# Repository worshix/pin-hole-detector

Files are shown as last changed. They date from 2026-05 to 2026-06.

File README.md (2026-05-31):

# PIN HOLE DETECTOR

A Django dashboard and ESP32-CAM firmware starter for capturing high-quality plastic roll images and storing them for future defect-model training.

## Firmware

Open `firmware/pinhole-detector-espcam/pinhole-detector-espcam.ino` in Arduino IDE.

Required Arduino libraries:

- ESP32 board package
- PubSubClient

Use board settings for an AI Thinker ESP32-CAM style module. The sketch connects to Wi-Fi `pinhole-detector`, listens to MQTT topic `pinhole/control`, and uploads JPEG frames to `http://192.168.137.1:8000/api/images/receive/` once per second after receiving `start`.

## Django app

```powershell
python -m venv .venv
.\.venv\Scripts\Activate.ps1
pip install -r requirements.txt
python manage.py migrate
python manage.py runserver 0.0.0.0:8000
```

Open `http://127.0.0.1:8000/` for the dashboard.

## MQTT

The dashboard publishes `start` and `stop` to topic `pinhole/control` on broker `192.168.137.1:1883`. Make sure Mosquitto is running and reachable from both the PC and ESP32-CAM.

## Image upload API

Endpoint: `/api/images/receive/`

The ESP32-CAM can post raw JPEG bytes with `Content-Type: image/jpeg`. Uploaded files are stored under `media/captures/` and shown on the dashboard/history pages.

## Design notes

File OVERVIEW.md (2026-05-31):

# Pinhole Detector In Plastic Roll

- We are using an esp32 to check for pinholes in a plastic roll.

## ESP32Pin Connections

| Pin | Component |
|-----|---|
| 4 | Light Relay |
| 5 | Motor (Moves the Plastic) |
| 18 | Start / Stop Button |
| 21 | SDA 20 x 4 LCD Display |
| 22 | SCL 20 x 4 LCD Display |
| 25  | Buzzer |
| 26 | Stop Indicator |
| 27 | Start Indicator |
| 34 | LDR 1  |
| 35 | LDR 2  |

## ESP32-CAM-MB
noconnections here just power

wifi name is "pinhole-detector"
wifi password is "pinhole123"
borker Ip Address is 192.168.137.1
I am using mosquitto broker for communication

## How it works

- The job of the esp32 is hole detection. If there is a hole the light will increase.
- Youy start by recording the ambient light then you start checking if light has increased. 
- We are using an LDR to detect the light.
- An increase in light means there has been a pinhole detected. If that happens you do not stop the motor but you do alert the user using buzzer and stop LED.
- The espcam is only used for taking pictures of the plastic every second and sending it to the application for dfect detection using A trained model
- esp32 cam only starts when taking pics when we hit start.
- It will get this information from the mqtt broker

## Application

- The application is made using django.
- The application has a dashboard showing the status of the esp32 and the images from the espcam
- The dashboard also displays a summary of all defects found and pinholes found. 
- The application also has a history page showing all the defects and pinholes found. 
-  All images should be stored in a folder as well.
-  I will finish the model training later but for now I need you to develop a full user interface and a route that receives images from esp32-cam-mb and stores them in a folder. 
- The route should be /api/images/receive
- I need high quality images so the model can be trained on them.
- There should also be a start and stop button on the dashboard to control the esp32.
- The esp32 should be able to send messages to the application via mqtt broker.
- The esp32 should be able to receive messages from the application via mqtt broker.

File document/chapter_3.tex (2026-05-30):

% Chapter 3: Methodology
% Required packages in main document: graphicx, float, geometry, setspace, hyperref

\chapter{Methodology}

\section{Introduction}

This chapter presents the methodology adopted in the design and development of the automated pinhole detection system for banknote paper quality control. The system integrates embedded hardware, computer vision, machine learning, and wireless communication technologies to achieve reliable and automated detection of pinholes in paper. The methodology covers the overall system architecture, the working principle of pinhole detection, the hardware components selected and their individual roles, the software design, and the mechanical structure of the system.

\section{System Architecture}

The system is composed of two main subsystems: a hardware detection unit and a software processing unit, which communicate over a Wi-Fi network.

The hardware detection unit consists of an ESP32 microcontroller, an ESP32-CAM module, a bright light source, Light Dependent Resistors (LDRs), a wiper motor, a relay module, a buck converter, a 12V power supply, and a 20$\times$4 I\textsuperscript{2}C LCD display. The wiper motor drives the paper through the detection chamber, where the bright light shines through the paper from one side while LDR sensors on the opposite side measure transmitted light intensity to detect pinholes.

The ESP32-CAM captures images of the paper under inspection and transmits them to the software unit via an HTTP API route over Wi-Fi. The software unit, running on a host computer, receives the images, processes them through a trained machine learning model built with Python, and returns detection results. The software communicates commands back to the detection hardware using the MQTT protocol, enabling real-time closed-loop control of the system.

\section{Working Principle of Pinhole Detection}

The fundamental principle behind the system is light transmission through pinholes. During normal operation, the bright light source illuminates one side of the banknote paper while the paper travels through the detection chamber driven by the wiper motor. Under a defect-free section of paper, the paper absorbs or scatters most of the light, resulting in a low reading at the LDR sensors on the opposite side.

When a pinhole is present in the paper, light passes directly through the hole and reaches the LDR sensors on the other side with a measurably higher intensity. This increase in detected light intensity triggers a detection event. The LDR readings are continuously monitored by the ESP32, which simultaneously operates the ESP32-CAM to capture an image of the suspect region. The image is then forwarded to the software system for further classification and confirmation via the trained machine learning model.

This dual approach — combining real-time LDR-based light sensing with image-based machine learning classification — ensures both speed and accuracy in pinhole detection.

\section{Hardware Components}

The following subsections describe each hardware component used in the system, its specifications, and its specific role in the detection process.

\subsection{Light Dependent Resistors (LDRs)}

\begin{figure}[H]
    \centering
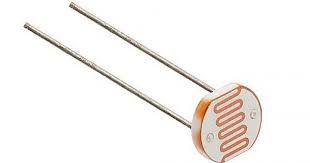
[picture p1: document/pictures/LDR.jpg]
    
    \caption{Light Dependent Resistor (LDR)}
    \label{fig:ldr}
\end{figure}

A Light Dependent Resistor (LDR), also known as a photoresistor, is a passive electronic component whose electrical resistance decreases as the intensity of incident light increases. As shown in Figure~\ref{fig:ldr}, the LDR is a compact, disc-shaped component with a characteristic serpentine conductive track on its surface.

In this system, LDRs are positioned on the side of the paper opposite to the bright light source. During normal scanning, the paper blocks most of the light and the LDRs register a high resistance (low voltage output). When light passes through a pinhole, the resistance of the corresponding LDR drops sharply, producing an elevated voltage that the ESP32 detects as an anomaly. Multiple LDRs are arranged across the width of the paper to provide full coverage of the inspection area.

\subsection{Bright Light Source}

\begin{figure}[H]
    \centering
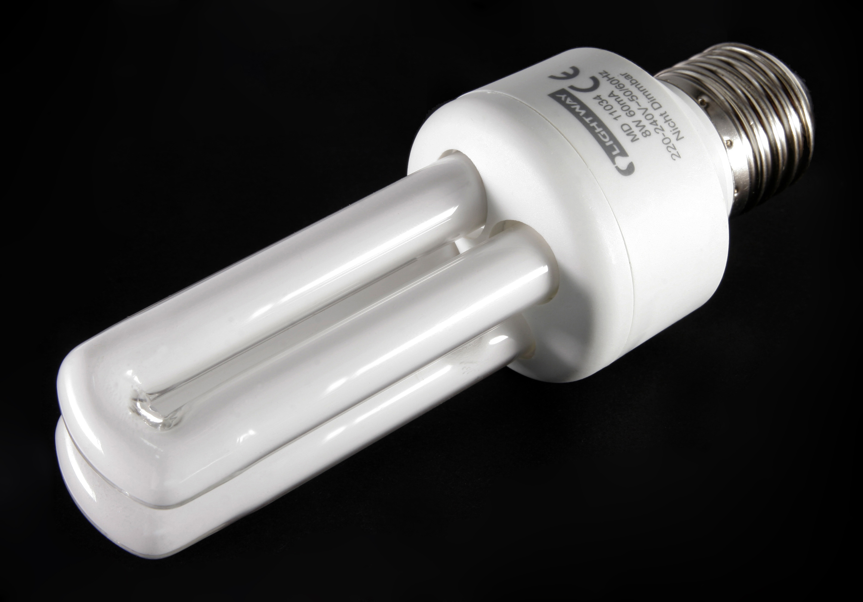
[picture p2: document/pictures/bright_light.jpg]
    
    \caption{Bright Light Source used for paper illumination}
    \label{fig:light}
\end{figure}

A high-intensity compact fluorescent lamp (CFL) is used as the light source, as shown in Figure~\ref{fig:light}. The bright light source is positioned on one side of the paper transport path, directing a uniform beam of light through the paper. A bright and consistent light source is essential to maximise the contrast between normal paper (which absorbs most of the light) and areas with pinholes (which allow the light to pass through). The CFL provides sufficient luminous intensity to ensure reliable LDR response and clear imaging by the ESP32-CAM.

\subsection{ESP32-CAM}

\begin{figure}[H]
    \centering
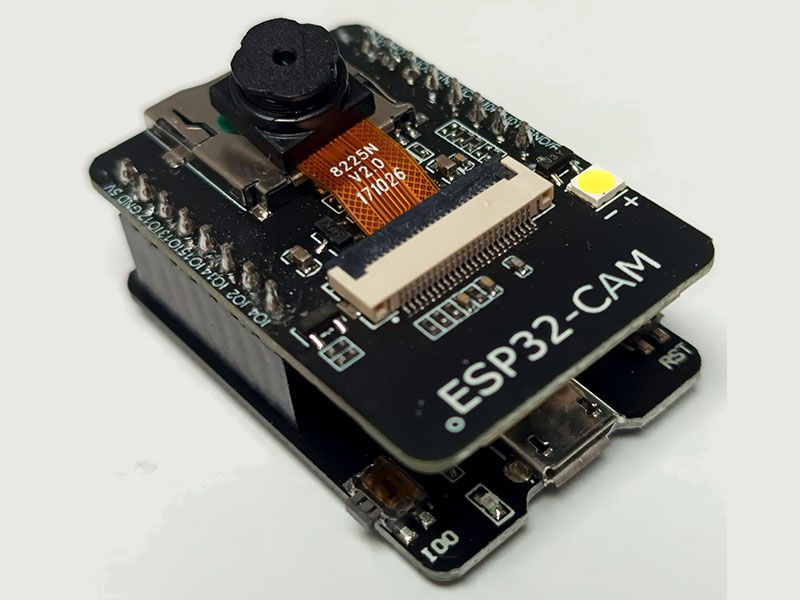
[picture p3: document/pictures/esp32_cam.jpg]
    
    \caption{ESP32-CAM Module}
    \label{fig:espcam}
\end{figure}

The ESP32-CAM, shown in Figure~\ref{fig:espcam}, is a small, low-cost microcontroller module that integrates an ESP32-S chip with an OV2640 camera and built-in Wi-Fi and Bluetooth capabilities. It is capable of capturing images and streaming video over a network.

In this system, the ESP32-CAM is mounted within the detection chamber and oriented to capture images of the paper surface during inspection. When triggered by the ESP32 (upon an LDR anomaly detection), the module captures a still image and transmits it to the host computer software via an HTTP POST request to a dedicated API endpoint. This allows the machine learning model to perform a secondary visual confirmation of detected pinholes.

\subsection{ESP32 Microcontroller}

\begin{figure}[H]
    \centering
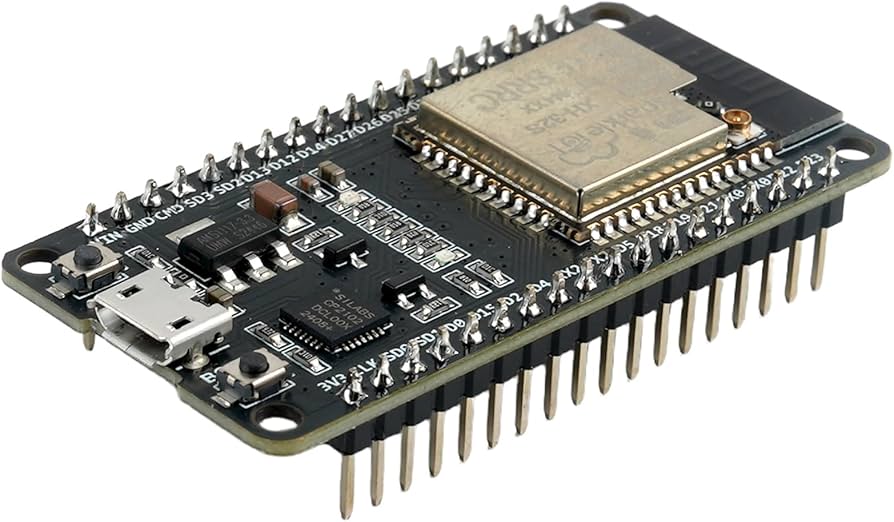
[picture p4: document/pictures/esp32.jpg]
    
    \caption{ESP32 Microcontroller}
    \label{fig:esp32}
\end{figure}

The ESP32, shown in Figure~\ref{fig:esp32}, is a powerful, low-cost, low-power system-on-chip (SoC) microcontroller with integrated Wi-Fi and Bluetooth. It features dual-core processing, numerous GPIO pins, ADC (Analogue-to-Digital Converter) channels, and support for multiple communication protocols including I\textsuperscript{2}C, SPI, UART, and MQTT.

The ESP32 serves as the central controller of the hardware unit. It reads the analogue output from the LDR sensors through its ADC channels, controls the relay module to manage the wiper motor, drives the LCD display to show system status and detection results, and communicates with the host software over Wi-Fi using the MQTT protocol. Upon receiving a detection command or result from the software, the ESP32 can trigger appropriate responses such as stopping the motor or flagging the defective paper section.

\subsection{Wiper Motor}

\begin{figure}[H]
    \centering
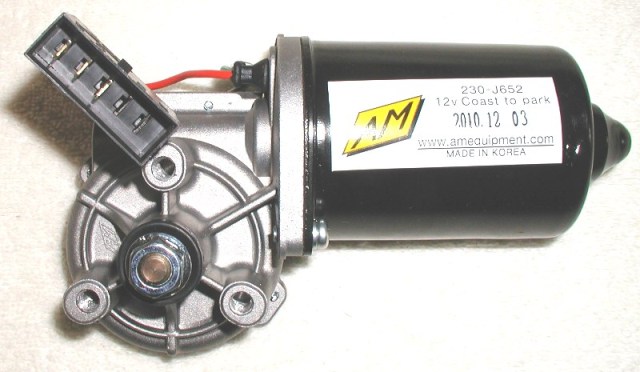
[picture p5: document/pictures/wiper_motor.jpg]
    
    \caption{Automotive Wiper Motor}
    \label{fig:wiper}
\end{figure}

An automotive wiper motor, shown in Figure~\ref{fig:wiper}, is used to drive the paper transport mechanism. Wiper motors are inherently designed to operate at low, consistent speeds — a characteristic that is essential for this application, as the paper must move slowly and uniformly through the detection chamber to allow sufficient time for the LDRs and ESP32-CAM to scan each section accurately.

The primary advantage of selecting a wiper motor over alternatives such as a standard DC motor with a Variable Frequency Drive (VFD) is that the wiper motor naturally operates at a low RPM without requiring additional speed-control circuitry. This simplifies the mechanical design and reduces overall system cost. The motor is powered by the 12V power supply and its operation is controlled via the relay module.

\subsection{Power Supply}

\begin{figure}[H]
    \centering
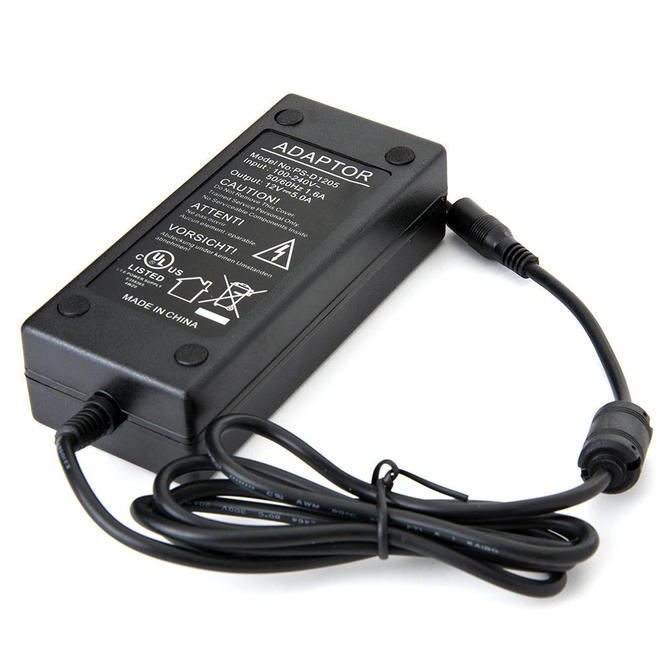
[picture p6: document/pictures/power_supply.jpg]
    
    \caption{12V DC Power Supply}
    \label{fig:psu}
\end{figure}

A 12V DC power supply, shown in Figure~\ref{fig:psu}, provides the primary power for the system. The 12V rail directly powers the wiper motor through the relay module. The same 12V supply also feeds the buck converter, which steps the voltage down to 5V for the ESP32 and other logic-level components. Using a single 12V supply for the entire system simplifies the power distribution architecture and reduces the number of external power adapters required.

\subsection{Relay Module}

\begin{figure}[H]
    \centering
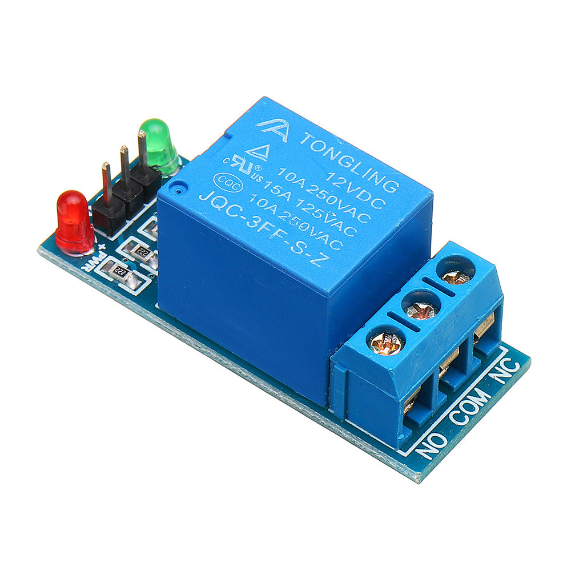
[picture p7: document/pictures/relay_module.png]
    
    \caption{12V Relay Module (5A)}
    \label{fig:relay}
\end{figure}

The relay module, shown in Figure~\ref{fig:relay}, is an electrically operated switch that allows the low-voltage ESP32 to control the high-voltage wiper motor circuit. The relay used is rated at 12V DC with a 5A current capacity, making it suitable for switching the wiper motor load safely.

When the ESP32 asserts a control signal to the relay's input pin, the relay coil is energised, closing the contact and completing the circuit between the 12V supply and the wiper motor. This enables the ESP32 to start and stop the motor as required during the detection process without any direct electrical connection between the microcontroller and the high-current motor circuit, thus protecting the ESP32 from voltage and current damage.

\subsection{\texorpdfstring{LCD 20$\times$4 I\textsuperscript{2}C Display}{LCD 20x4 I2C Display}}

\begin{figure}[H]
    \centering
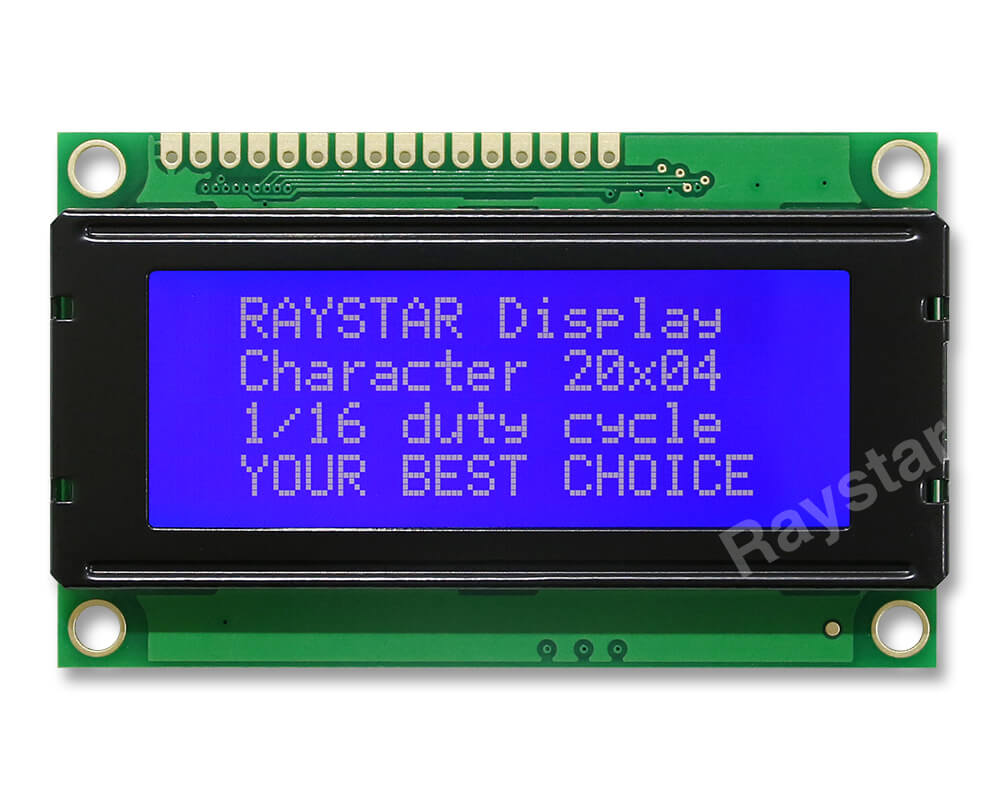
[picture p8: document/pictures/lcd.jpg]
    
    \caption{20$\times$4 Character LCD with I\textsuperscript{2}C Interface}
    \label{fig:lcd}
\end{figure}

The 20$\times$4 character LCD module with I\textsuperscript{2}C interface, shown in Figure~\ref{fig:lcd}, provides a local user interface for the detection system. The display is capable of showing 4 rows of 20 characters each, which is sufficient to present system status messages, detection results, motor state, and Wi-Fi connectivity information.

The I\textsuperscript{2}C interface requires only two signal lines (SDA and SCL) to communicate with the ESP32, minimising the number of GPIO pins used. This is particularly advantageous given that the ESP32 must also manage the LDR ADC channels, relay control, and MQTT communication simultaneously.

\subsection{Buck Converter}

\begin{figure}[H]
    \centering
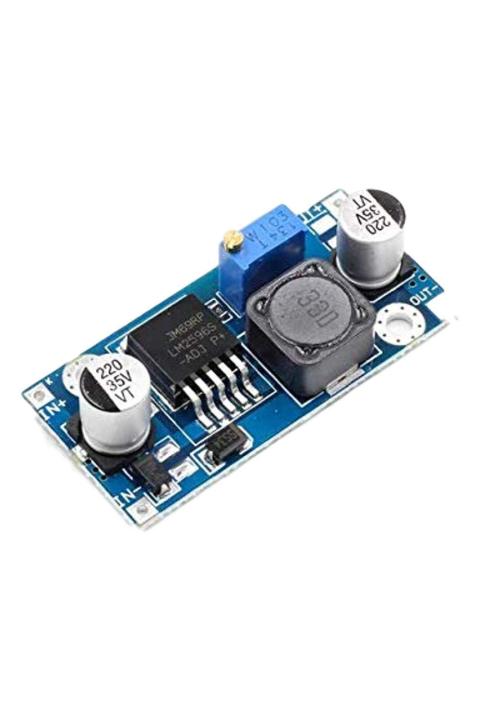
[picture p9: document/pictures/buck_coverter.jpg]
    
    \caption{DC-DC Buck Converter (12V to 5V)}
    \label{fig:buck}
\end{figure}

A DC-DC buck converter, shown in Figure~\ref{fig:buck}, is a step-down voltage regulator that efficiently converts the 12V supply voltage to the 5V required by the ESP32 microcontroller and other logic-level components. Unlike linear regulators, a buck converter achieves voltage step-down with high efficiency (typically above 85\%), generating significantly less heat and wasting less power, which is important for a continuously running embedded system.

The buck converter takes the 12V input from the primary power supply and outputs a regulated 5V to power the ESP32, LCD module, and relay control circuitry, ensuring stable operation of all electronic components throughout the detection process.

\section{Software Design}

The software subsystem is responsible for receiving images from the ESP32-CAM, classifying them using a trained machine learning model, and returning detection results to the hardware via MQTT. The software runs on a host computer connected to the same Wi-Fi network as the ESP32 and ESP32-CAM.

\subsection{Flask Web Server and API}

The software is built using Flask, a lightweight Python web framework. Flask exposes a RESTful HTTP API with a dedicated endpoint to which the ESP32-CAM sends captured images. Upon receiving an image via an HTTP POST request to the API route, the server immediately passes the image to the machine learning inference module for processing. Flask was selected for its simplicity, minimal overhead, and ease of integration with Python-based machine learning libraries.

\subsection{Machine Learning Model}

A machine learning model is trained using Python to classify captured images as either containing a pinhole or being defect-free. The model is trained on a labelled dataset of paper images, learning the visual signatures associated with pinholes under the system's lighting conditions. Once trained, the model is serialised and loaded by the Flask application at startup, ready for real-time inference on incoming images from the ESP32-CAM.

\subsection{MQTT Communication}

The Message Queuing Telemetry Transport (MQTT) protocol is used for communication from the software back to the ESP32 hardware. After the machine learning model produces a classification result, the Flask server publishes the result as an MQTT message to a broker. The ESP32, subscribed to the relevant MQTT topic, receives the message and takes the appropriate action, such as stopping the wiper motor or displaying an alert on the LCD. MQTT was chosen for its low bandwidth usage, low latency, and suitability for embedded IoT applications.

\section{Mechanical Design}

The mechanical structure of the detection system was designed using SolidWorks, a professional 3D computer-aided design (CAD) software package. The design encapsulates the paper transport mechanism, the light source housing, the LDR mounting array, the camera mount, and the electronics enclosure into a single integrated unit.

The wiper motor is mechanically coupled to a roller mechanism that drives the banknote paper through the detection chamber at a controlled, low speed. The light source is positioned on one side of the paper path within a sealed housing to prevent ambient light from interfering with LDR readings. The LDR array is mounted directly opposite the light source on a fixed bracket to maintain consistent sensor-to-paper distance during operation.

The SolidWorks model allowed for precise dimensioning and assembly verification before physical fabrication, reducing the risk of component fit issues and ensuring that the optical alignment between the light source, paper, and LDR sensors was maintained accurately throughout operation.

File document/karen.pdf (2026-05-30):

# Chapter 1

# Methodology

## 1.1 Introduction

This chapter presents the methodology adopted in the design and development of the

automated pinhole detection system for banknote paper quality control. The system

integrates embedded hardware, computer vision, machine learning, and wireless commu-

nication technologies to achieve reliable and automated detection of pinholes in paper.

The methodology covers the overall system architecture, the working principle of pin-

hole detection, the hardware components selected and their individual roles, the software

design, and the mechanical structure of the system.

## 1.2 System Architecture

The system is composed of two main subsystems: a hardware detection unit and a soft-

ware processing unit, which communicate over a Wi-Fi network.

The hardware detection unit consists of an ESP32 microcontroller, an ESP32-CAM

module, a bright light source, Light Dependent Resistors (LDRs), a wiper motor, a relay

module, a buck converter, a 12V power supply, and a 20×4 I²C LCD display. The

wiper motor drives the paper through the detection chamber, where the bright light

shines through the paper from one side while LDR sensors on the opposite side measure

transmitted light intensity to detect pinholes.

The ESP32-CAM captures images of the paper under inspection and transmits them

to the software unit via an HTTP API route over Wi-Fi. The software unit, running on

a host computer, receives the images, processes them through a trained machine learning

model built with Python, and returns detection results. The software communicates

commands back to the detection hardware using the MQTT protocol, enabling real-time

closed-loop control of the system.

## 1.3 Working Principle of Pinhole Detection

The fundamental principle behind the system is light transmission through pinholes.

During normal operation, the bright light source illuminates one side of the banknote

paper while the paper travels through the detection chamber driven by the wiper motor.

Under a defect-free section of paper, the paper absorbs or scatters most of the light,

resulting in a low reading at the LDR sensors on the opposite side.

When a pinhole is present in the paper, light passes directly through the hole and

reaches the LDR sensors on the other side with a measurably higher intensity. This

increase in detected light intensity triggers a detection event. The LDR readings are

continuously monitored by the ESP32, which simultaneously operates the ESP32-CAM

to capture an image of the suspect region. The image is then forwarded to the software

system for further classification and confirmation via the trained machine learning model.

This dual approach — combining real-time LDR-based light sensing with image-based

machine learning classification — ensures both speed and accuracy in pinhole detection.

## 1.4 Hardware Components

The following subsections describe each hardware component used in the system, its

specifications, and its specific role in the detection process.

### 1.4.1 Light Dependent Resistors (LDRs)


Figure 1.1: Light Dependent Resistor (LDR)

A Light Dependent Resistor (LDR), also known as a photoresistor, is a passive elec-

tronic component whose electrical resistance decreases as the intensity of incident light

increases. As shown in Figure 1.1, the LDR is a compact, disc-shaped component with a

characteristic serpentine conductive track on its surface.

In this system, LDRs are positioned on the side of the paper opposite to the bright

light source. During normal scanning, the paper blocks most of the light and the LDRs

register a high resistance (low voltage output). When light passes through a pinhole, the

resistance of the corresponding LDR drops sharply, producing an elevated voltage that

the ESP32 detects as an anomaly. Multiple LDRs are arranged across the width of the

paper to provide full coverage of the inspection area.

### 1.4.2 Bright Light Source


Figure 1.2: Bright Light Source used for paper illumination

A high-intensity compact fluorescent lamp (CFL) is used as the light source, as shown

in Figure 1.2. The bright light source is positioned on one side of the paper transport

path, directing a uniform beam of light through the paper. A bright and consistent light

source is essential to maximise the contrast between normal paper (which absorbs most

of the light) and areas with pinholes (which allow the light to pass through). The CFL

provides sufficient luminous intensity to ensure reliable LDR response and clear imaging

by the ESP32-CAM.

### 1.4.3 ESP32-CAM


Figure 1.3: ESP32-CAM Module

The ESP32-CAM, shown in Figure 1.3, is a small, low-cost microcontroller module that

integrates an ESP32-S chip with an OV2640 camera and built-in Wi-Fi and Bluetooth

capabilities. It is capable of capturing images and streaming video over a network.

In this system, the ESP32-CAM is mounted within the detection chamber and oriented

to capture images of the paper surface during inspection. When triggered by the ESP32

(upon an LDR anomaly detection), the module captures a still image and transmits it to

the host computer software via an HTTP POST request to a dedicated API endpoint.

This allows the machine learning model to perform a secondary visual confirmation of

detected pinholes.

### 1.4.4 ESP32 Microcontroller

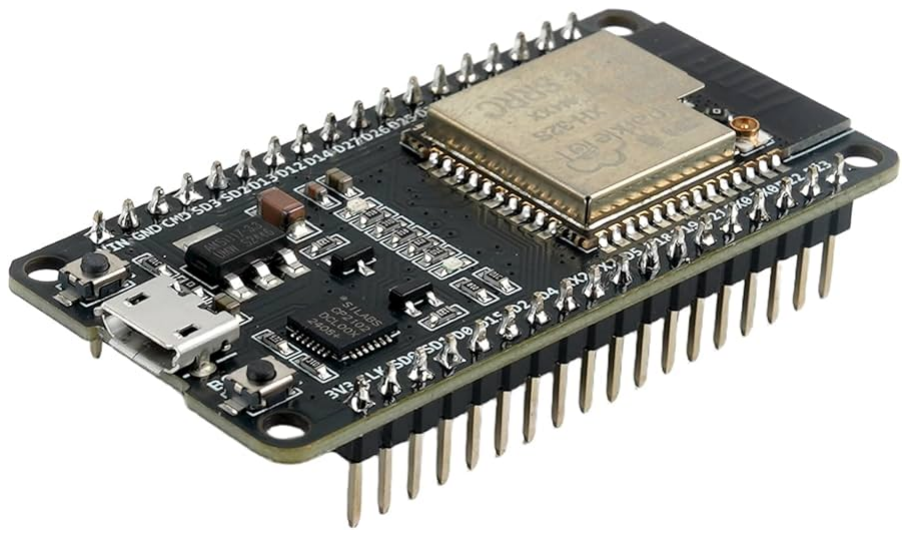
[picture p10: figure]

Figure 1.4: ESP32 Microcontroller

The ESP32, shown in Figure 1.4, is a powerful, low-cost, low-power system-on-chip (SoC)

microcontroller with integrated Wi-Fi and Bluetooth. It features dual-core processing,

numerous GPIO pins, ADC (Analogue-to-Digital Converter) channels, and support for

multiple communication protocols including I²C, SPI, UART, and MQTT.

The ESP32 serves as the central controller of the hardware unit. It reads the analogue

output from the LDR sensors through its ADC channels, controls the relay module to

manage the wiper motor, drives the LCD display to show system status and detection

results, and communicates with the host software over Wi-Fi using the MQTT protocol.

Upon receiving a detection command or result from the software, the ESP32 can trigger

appropriate responses such as stopping the motor or flagging the defective paper section.

### 1.4.5 Wiper Motor


Figure 1.5: Automotive Wiper Motor

An automotive wiper motor, shown in Figure 1.5, is used to drive the paper transport

mechanism. Wiper motors are inherently designed to operate at low, consistent speeds

— a characteristic that is essential for this application, as the paper must move slowly

and uniformly through the detection chamber to allow sufficient time for the LDRs and

ESP32-CAM to scan each section accurately.

The primary advantage of selecting a wiper motor over alternatives such as a standard

DC motor with a Variable Frequency Drive (VFD) is that the wiper motor naturally op-

erates at a low RPM without requiring additional speed-control circuitry. This simplifies

the mechanical design and reduces overall system cost. The motor is powered by the 12V

power supply and its operation is controlled via the relay module.

### 1.4.6 Power Supply


Figure 1.6: 12V DC Power Supply

A 12V DC power supply, shown in Figure 1.6, provides the primary power for the system.

The 12V rail directly powers the wiper motor through the relay module. The same

12V supply also feeds the buck converter, which steps the voltage down to 5V for the

ESP32 and other logic-level components. Using a single 12V supply for the entire system

simplifies the power distribution architecture and reduces the number of external power

adapters required.

### 1.4.7 Relay Module

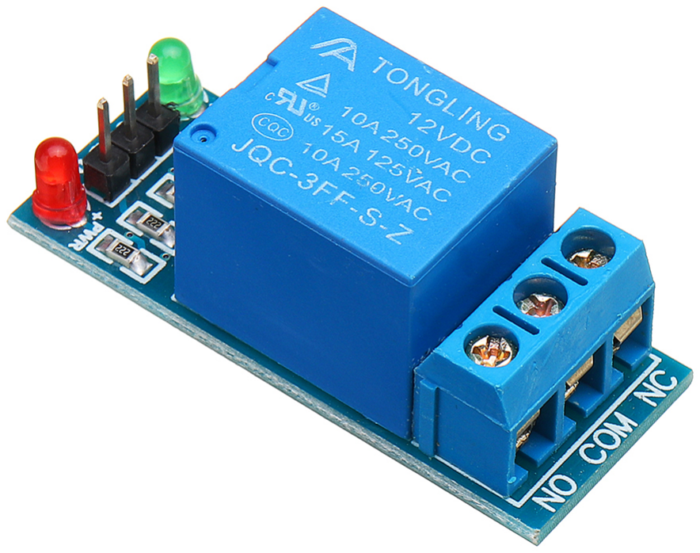
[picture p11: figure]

Figure 1.7: 12V Relay Module (5A)

The relay module, shown in Figure 1.7, is an electrically operated switch that allows the

low-voltage ESP32 to control the high-voltage wiper motor circuit. The relay used is

rated at 12V DC with a 5A current capacity, making it suitable for switching the wiper

motor load safely.

When the ESP32 asserts a control signal to the relay’s input pin, the relay coil is

energised, closing the contact and completing the circuit between the 12V supply and the

wiper motor. This enables the ESP32 to start and stop the motor as required during the

detection process without any direct electrical connection between the microcontroller

and the high-current motor circuit, thus protecting the ESP32 from voltage and current

damage.

### 1.4.8 LCD 20×4 I²C Display


Figure 1.8: 20×4 Character LCD with I²C Interface

The 20×4 character LCD module with I²C interface, shown in Figure 1.8, provides a local

user interface for the detection system. The display is capable of showing 4 rows of 20

characters each, which is sufficient to present system status messages, detection results,

motor state, and Wi-Fi connectivity information.

The I²C interface requires only two signal lines (SDA and SCL) to communicate with

the ESP32, minimising the number of GPIO pins used. This is particularly advantageous

given that the ESP32 must also manage the LDR ADC channels, relay control, and

MQTT communication simultaneously.

### 1.4.9 Buck Converter


Figure 1.9: DC-DC Buck Converter (12V to 5V)

A DC-DC buck converter, shown in Figure 1.9, is a step-down voltage regulator that effi-

ciently converts the 12V supply voltage to the 5V required by the ESP32 microcontroller

and other logic-level components. Unlike linear regulators, a buck converter achieves volt-

age step-down with high efficiency (typically above 85%), generating significantly less heat

and wasting less power, which is important for a continuously running embedded system.

The buck converter takes the 12V input from the primary power supply and outputs

a regulated 5V to power the ESP32, LCD module, and relay control circuitry, ensuring

stable operation of all electronic components throughout the detection process.

## 1.5 Software Design

The software subsystem is responsible for receiving images from the ESP32-CAM, clas-

sifying them using a trained machine learning model, and returning detection results to the hardware via MQTT. The software runs on a host computer connected to the same

Wi-Fi network as the ESP32 and ESP32-CAM.

### 1.5.1 Flask Web Server and API

The software is built using Flask, a lightweight Python web framework. Flask exposes a

RESTful HTTP API with a dedicated endpoint to which the ESP32-CAM sends captured

images. Upon receiving an image via an HTTP POST request to the API route, the server

immediately passes the image to the machine learning inference module for processing.

Flask was selected for its simplicity, minimal overhead, and ease of integration with

Python-based machine learning libraries.

### 1.5.2 Machine Learning Model

A machine learning model is trained using Python to classify captured images as either

containing a pinhole or being defect-free. The model is trained on a labelled dataset of

paper images, learning the visual signatures associated with pinholes under the system’s

lighting conditions. Once trained, the model is serialised and loaded by the Flask applica-

tion at startup, ready for real-time inference on incoming images from the ESP32-CAM.

### 1.5.3 MQTT Communication

The Message Queuing Telemetry Transport (MQTT) protocol is used for communication

from the software back to the ESP32 hardware. After the machine learning model pro-

duces a classification result, the Flask server publishes the result as an MQTT message

to a broker. The ESP32, subscribed to the relevant MQTT topic, receives the message

and takes the appropriate action, such as stopping the wiper motor or displaying an alert

on the LCD. MQTT was chosen for its low bandwidth usage, low latency, and suitability

for embedded IoT applications.

## 1.6 Mechanical Design

The mechanical structure of the detection system was designed using SolidWorks, a pro-

fessional 3D computer-aided design (CAD) software package. The design encapsulates

the paper transport mechanism, the light source housing, the LDR mounting array, the

camera mount, and the electronics enclosure into a single integrated unit.

The wiper motor is mechanically coupled to a roller mechanism that drives the ban-

knote paper through the detection chamber at a controlled, low speed. The light source

is positioned on one side of the paper path within a sealed housing to prevent ambient

light from interfering with LDR readings. The LDR array is mounted directly opposite

the light source on a fixed bracket to maintain consistent sensor-to-paper distance during

operation.

The SolidWorks model allowed for precise dimensioning and assembly verification

before physical fabrication, reducing the risk of component fit issues and ensuring that

the optical alignment between the light source, paper, and LDR sensors was maintained

accurately throughout operation.

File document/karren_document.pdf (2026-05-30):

KAREN SITHEMBILE SIBANDA
H210471G

HIT 400
PTE 2026

# CHAPTER ONE: INTRODUCTION

## 1.1 TITLE

Design and development of a Vision-Based Pinhole Detection system for Blown Film Extrusion

Lines of food packaging materials.

## 1.2 BACKGROUND

Blown film extrusion is widely used for manufacturing plastic films for food packaging.

Pinholes can lead to contamination, spoilage and reduced shelf life of packaged goods. In food

applications, such defects are unacceptable. This project proposes the integration of a real-time

optical inspection system into a blown film line to detect pinholes in polymer films ranging

from 15-90 micron in thickness.

This project was inspired by a real industrial challenge I encountered during my internship at

PE Plastics, a company that manufactures food packaging material using blown film extrusion.

One of the extruders consistently produced rolls with undetected pinholes. These pinholes

where invisible during the extrusion process and their presence was only discovered during

downstream use particularly when hot liquids leaked through the pinholes during auto-pack

operations.

The auto-pack was for ‘mahewu’, mahewu is packed whilst hot. When hot liquid was dispensed

into the packaging, it would leak or gush out through these tiny pinholes, resulting in significant

product loss, compromised hygiene and customer dissatisfaction. Due to the absence of an in-

line detection system capable of identifying such micro-defects in real time, the only short-

term solution was to completely stop using that particular extruder, leading to down time and

production inefficiencies.

This experience highlighted the critical importance of early pinhole detection in food packaging

applications, where even microscopic defects can cause major quality and safety issues. It also

HIT 400
PTE 2026

revealed a gap in process automation and quality control, particularly in environments where

visual inspection is impractical or unreliable due to high-speed production.

Motivated by this experience, I decided to focus my HIT400 project on developing a low-cost

vision-based pinhole detection system for blown film extrusion. The goal is to create a solution

that can be integrated directly into the production line, capable of identifying pinholes in real

time before the film reaches the winding stage. By addressing this problem, the project aims to

enhance product reliability, minimize waste and improve overall quality assurance in the

manufacturing of food packaging materials.

## 1.3 PROBLEM STATEMENT

Current quality control in blown film extrusion largely relies on manual visual inspection or

offline testing methods that fail to identify pinholes during production. This delay results in

waste, production downtime and the potential distribution of defective food packaging

materials. Existing automated detection technologies are often expensive, proprietary and

inaccessible for small to medium manufacturers or academic applications.

There is therefore a critical need for an affordable, open-source and real-time vision-based

system capable of detecting microscopic pinholes in thin (15-90µm) polyethylene films during

extrusion.

## 1.4 AIM

To design and implement a camera-based vision system capable of detecting pinholes during

production, ensuring the integrity and safety of food packaging materials in real time.

HIT 400
PTE 2026

## 1.5 OBJECTIVES

- To design a low-cost, non-contact optical detection system using a high-resolution

camera and backlight to identify pinholes during production.

- To develop image processing software capable of detecting, classifying and recording

pinhole defects in real-time.

- To test and evaluate the effectiveness of the detection system under controlled

conditions using film samples with known defects.

___________________________________________________________________________

## 1.6 JUSTIFICATION

The production of blown film for food packaging requires strict quality control because defects

such as pinholes can compromise barrier properties, resulting in contamination, reduced shelf

life, and potential health risks to consumers. Pinhole defects may arise from gel formation, melt

instability, contamination, or mechanical damage during processing (Ding, Hobbs &

Bhattacharya, 2014). In food packaging applications, even microscopic perforations can allow

oxygen or microorganisms to penetrate the product, undermining food safety systems.

Therefore, implementing an automated, camera-based pinhole detection system is essential to

ensure consistent quality, reduce material waste, and prevent defective products from reaching

the market.

In Zimbabwe, food safety management systems are guided by national standards such as ZWS

749: Requirements for a Hazard Analysis and Critical Control Point (HACCP) system,

which outlines preventive approaches to identifying and controlling hazards within the food

supply chain (Standards Association of Zimbabwe, 2024). Since packaging materials form part

of the food safety chain, defects in polymer films can represent a potential hazard if not

adequately controlled. The Standards Association of Zimbabwe (SAZ) also provides accredited

certification services aligned with HACCP and ISO-based food safety systems (Standards

Association of Zimbabwe, no date). By integrating a vision-based defect detection system into

the blown film extrusion line, this project supports HACCP principles by introducing a

HIT 400
PTE 2026

preventive monitoring mechanism at a critical control stage. Furthermore, vision-based

inspection technologies have been shown to significantly improve defect detection accuracy

and reliability in polymer film manufacturing (Rawashdeh, Hazaveh & Altarazi, 2023; Szeliski,

2022). Consequently, this research is necessary to enhance food packaging safety, ensure

compliance with Zimbabwean regulatory standards, and improve overall manufacturing

efficiency and product integrity.

___________________________________________________________________________

## 1.7 SCOPE OF STUDY

This study focuses on the design, development and evaluation of a pinhole detection system for

blown film extrusion lines producing food-grade polymer films ranging from 15 to 90 microns

in thickness. The research is confined to the implementation of an optical inspection system

using image-based technology for real-time detection of pinholes during the manufacturing

process.

I) Identification of causes of pinholes

Investigating common sources of pinhole defects in blown film, including raw

material impurities, melt inconsistency, air contamination and process disturbances.

II) | Selection of suitable detection technology
| Evaluating and selecting appropriate optical components such as industrial cameras
| and lighting systems capable of detecting micron-level defects in transparent or
| semi-transparent films.
III) | System design and integration
| Designing a mounting and alignment system for camera and backlight integration
| into the existing blown film line, preferably in the flat film zone (post-nip rollers)
IV) | Image processing and analysis
| Developing or applying software algorithms (e.g. thresholding, blob detection) to
| identify and quantify pinholes in real-time.

HIT 400
PTE 2026
V) Prototype testing and calibration

Testing the system using known pinhole sizes and real production samples to assess

accuracy, sensitivity and reliability.

VI) | Evaluation of effectiveness
| Measuring the system’s performances in terms of ✓ Minimum detectable hole size
| ✓ False positives or negatives
| ✓ Speed compatibility with line throughput
VII) | Limitations and industrial scalability
| Assessing constraints such as lighting uniformly, speed limitations and film
| movement and suggesting improvement for future industrial-scale applications.

___________________________________________________________________________

HIT 400
PTE 2026

# CHAPTER TWO: LITERATURE REVIEW

## 2.1 Introduction

Blown film extrusion is widely used to manufacture polymer films for packaging, including

food packaging where barrier integrity is critical. A blown film line extrudes a polymer tube

which is inflated to form a bubble, cooled and flattened into rolls. Defects such as pinholes,

gels, contamination specks, gauge variation, haze, die lines and melt fracture degrade

performance and may compromise barrier properties, product appearance and food safety.

Detecting pinholes (microscopic through-holes or perforations) is particularly important in

food packaging because even tiny pinholes can permit oxygen or moisture ingress that shortens

shelf life or causes contamination. Online detection that is accurate at high line speeds is

therefore essential for quality control. This review focuses on how pinholes and other defects

have been detected on blown film extrusion lines, surveying both manual/visual inspection and

automated, vision—based and sensor-based systems.

## 2.2 Blown film extrusion: process overview and defect taxonomy

a) Process summary

The blown film process melts polymer resin and extrudes it through a circular die. The extruded

tube is inflated via annular air ring, cooled across a frost line, collapsed by nip rollers, and

wound. Process variables include resin grade, melt temperature profile, die design, cooling rate,

blow-up ratio, nip roll settings, and winding tension, each of which can influence defect

formation.(“HOW TO SOLVE BLOWN FILM PROBLEMS,” n.d.)

b) Defect types (typology and significance)

Common defects in blown film include:

- Pinholes/micro-holes: through-film perforations (critical for barrier films).
- Gels: un-melted resin particles causing visual blemishes and weak spots
- Contamination specks: foreign particles causing visible dark specks or thin

spots.

- Gauge/thickness variation: nonuniform film thickness that affects

mechanical properties.

- Haze/cloudiness: optical defects affecting appearance.
- Die lines/sharkskin/melt fracture: surface irregularities from rheological

instabilities.

- Burn marks, black specks: thermal degradation or char particles. (“HOW

TO SOLVE BLOWN FILM PROBLEMS,” n.d.)

Each defect class has different detection challenges: pinholes require transmission detection to

detect light passing through; specks and gels are often visible in reflection; gauge variation

benefits from thickness metrology sensors; haze requires optical characterization. (Rawashdeh

et al., 2023)

### 1. Manual (human) inspection vs automated inspection

a) Manual inspection

Historically, quality control relied on operator visual inspection at roll change off-line checks

(e.g., feel, light table inspection) and occasional laboratory tests. Manual methods are

subjective, fatiguing, and incompatible with high line speeds and the need for consistent

detection thresholds. Reports and industry guides emphasize the limitations of manual

inspection for micro-defects and continuous process control.(“HOW TO SOLVE BLOWN

FILM PROBLEMS,” n.d.)

b) Automated inspection: motivations and benefits

Automated systems provide consistent detection thresholds, logging, high-throughput

screening and integration with process control. Automated inspection also enables 100% in-

line inspection (scan every meter of film), rapid rejection of defective batches, and feedback

for process tuning. For pinholes in particular, automated transmission inspection systems

provide detection sensitivity beyond human capability at production speeds.(“pinhole

inspection units,” n.d.)

### 2.2.2 Sensing modalities for pinhole and general defect detection

Detection approaches fall into several sensor/ illumination categories:

a) Transmission/backlight (full-field or line) imaging

Backlight (transmission) inspection places a uniform light source behind the film and images the film’s transmitted light. Pinholes and thin areas allow more light through and appear as

bright spots in transmitted images. Transmission is the most common and effective method for

pinhole detection because it directly measures through-film light passage; manufacturer units

and commercial pinholes detectors use carefully controlled low-noise photonic sensors and

ring/backlight illumination to detect micro-perforations as small as 1µm under optimal

conditions.

Key design considerations: uniform illumination, sensor dynamic range, optical resolution

versus line speed, stray light suppression and wide field coverage (to inspect the entire film

width).

High sensitivity cameras or photodiode arrays are often used.

b) Low-light/photonics detectors and high dynamic range sensors

Some systems leverage photomultiplier or low-light CMOS sensors with high gain to detect

very small pinholes, especially under low ambient light and for metallized or opaque films

where contrast is low.

c) Reflective vision and inspection (for surface defects)

Reflective imaging with structured illumination or grazing incidence is better suited for surface

defects such as gels, contamination or die lines. Combined systems using both reflective and

transmissive imaging can detect a broader and set of defects.

d) Thermography and IR

Thermographic imaging (e.g., active thermography) reveals subsurface defects by heating and

observing thermal response; some studies apply thermography with ANN classification for

pinhole or subsurface void detection in films/coatings. Thermography tends to be used in

research or specific industrial contexts rather than standard blown film lines because of

complexity and slower acquisition.

e) Densitometry/transmission densitometers

Full-field transmission densitometry measures transmitted light intensity across the film and

has been used to detect thin spots and pinholes in cast or metallized films; it may be combined

with machine vision for localization.

f) Electrical or leak testing

For finished packages, leak testing (e.g., pressure decay, bubble testing in liquid baths,

conductive tests) is common; however, these are typically offline or after forming (e.g., blister

packs) and less suitable for continuous blown film inspection prior to conversion.

### 2.2.3 Image acquisition & illumination engineering

Accurate pinhole detection depends more on acquisition optics and lighting than on

classification algorithms alone. Key factors documented in industry and research sources

include:

- Backlight | uniformity: | uneven | backlight | creates | false | positives/negatives.

Manufacturers design diffusers, collimated LED arrays and integrating cavities for

uniformity.

- Spectral selection: choosing wavelengths where the film attenuates helps increase

contrast; for metallized films near-IR or specific narrowband lighting may improve

detection.

- Sensor noise and dynamic range: high dynamic range is necessary to detect tiny

transmission differences without saturation at bright regions; some vendors use

dedicated low-noise sensors.

- Optical resolution: optics must resolve the smallest defect size of interest; Nyquist

sampling considerations dictate pixel pitch and lens quality.

- Industrial pinhole detection modules from Hamamatsu and Antares describe engineered

illumination and sensor packages optimized for these needs.

### 2.2.4 Image processing and machine learning methods

a) Traditional image processing

Early systems used straightforward image processing pipelines: flat-field correction,

background subtraction, adaptive thresholding, morphological filtering, connected component

analysis, and heuristic size/shape filters to eliminate noise. For transmission images, simple

thresholding on transmitted intensity identifies candidate pinholes which are then

morphologically processed to remove speckle noise. These methods work well when lighting

is uniform and defect contrast is high.

b) Statistical and transform methods

Fourier and wavelet analyses, texture measures, and statistical filters have been used to separate

defect structures from patterned texture. For certain film textures, frequency filtering helps

suppress periodic noise (e.g., weave patterns of films) and reveal localized defects.

c) Machine learning and neural networks

More recent work applies machine learning and deep learning to reduce false positives and

classify defect types. Convolutional neural networks (CNNs) and hybrid architectures have

been trained (often on labeled datasets) to recognize pinholes, gels and contamination. Several

academic studies and industry systems use ML for post-processing after traditional detection

to cluster and classify defect candidates, improving precision at the cost of requiring labeled

training data. A 2023 vision-based online defect detection study demonstrated ML integration

for polymeric films and argued for real-time feasibility.

d) Hybrid approaches

Best practice is to combine simple, fast image processing (for initial candidate detection) with

ML classification to filter false positives. This limits computation load and enables real-time

performance at industrial speeds. Systems may also employ change detection and temporal

voting across consecutive frames to confirm transient defects versus noise.

### 2. Causes of pinholes

Multiple consistent root causes for pinholes are reported across patents, manufacturer notes

and technical literature:

- Contaminants/particles: dust or foreign particles entrained in the melt or landing

on film during winding can create pinholes (particle exclusion zones or pick-

off).

- Volatile substances / outgassing: residual solvents, moisture or volatile

additives can vaporize during extrusion or later thermal processes, causing

bubbles that burst and leave pinholes. Patents and technical notes emphasize

volatile entrainment as a key mechanism.

- Poor dispersion or un-melted resin: incomplete melting or poor dispersion can

create weak spots and voids that develop into pinholes.

- Winding / re-winding adhesion (pick-off): metal transfer or adhesion issues

during rewinding may pull small pieces away and create pinholes, especially in

metallized films.

- Temperature control issues: improper heater zone settings, inadequate mixing,

or too-low melt temperatures cause poor melt quality and pinholing. Industry

troubleshooting guidance lists heater profile and screen damage as common

causes.

Because causes are varied, prevention requires good material handling, melt filtration, controlled drying to remove moisture/volatile content, correct temperature profiles and

maintenance of filtering/screens.

## 2.3 Detection of other defects and their detection methods

- Gels and contamination: reflective imaging with controlled lighting and high

resolution is effective; algorithms use contrast enhancement and blob detection.

- Gauge variation: thickness gauges (beta gauges, infrared thickness meters, laser

triangulation) and full-field thickness mapping are used. Vision systems may

infer thickness variations using structured light or transmission densitometry.

- Haze/optical quality: haze meters and optical scatter methods quantify haze;

vision systems estimate image contrast and scatter metrics.

- Die lines / melt fracture: high-resolution line-scan cameras with reflective

imaging detect linear features; temporal analysis tracks repeatability.

Combining multiple sensor types extends detection coverage across defect classes. Several

vendors provide modular systems that combine backlight and reflective cameras to

simultaneously find pinholes and surface defects.

## 2.4 Commercial solutions and industrial practice

A number of vendors provide dedicated pinhole inspection hardware or full film inspection

systems for converting lines:

Hamamatsu: manufactures pinhole inspection units and low-light photonics units claiming

detection down to micrometer scales, suitable for roll-to-roll inspection at high speed.

Antares Vision Group: offers pinhole detection and inspection systems for laminated films and

pharmaceutical packaging; integrates AI and industrial sensors.

Erhardt+Leimer: SMARTSCAN 200% inspection with pinhole detection for converting

industry.

Others: specialized suppliers (Jornen, Patera/Scanware, QUALISHIELD by ACG) supply both

off-the-shelf and custom inspection units targeted to blister packs, foil, and film converting.

Industrial systems emphasize integration with line control (e.g., stop/fail signals, reject

triggers) and operate at typical converting speeds with real-time throughput. Performance

claims vary by vendor.

## 2.5 Performance metrics and challenges

a) Accuracy, sensitivity, and false positives

Sensitivity: detecting very small pinholes (sub-10 µm) requires high optical resolution and high

signal-to-noise ratio; vendor claims vary (some claim 1 µm under ideal conditions).

False positives: dust, specular highlights, wrinkles and winding defects can generate false

alarms; post-processing, temporal confirmation and ML classification are used to reduce false

alarms.

b) Throughput and real-time constraints

At industrial line speeds (meters per minute to hundreds of m/min), image readout, processing

and I/O must meet tight latency budgets. Line-scan cameras or parallel multi-camera arrays are

common solutions; architectures that perform fast initial filtering in FPGA or edge devices

followed by more sophisticated analysis on CPU/GPU are used.

c) Material variability and environmental conditions

Differences in film thickness, opacity, colors, metallization, and winding tension lead to

variability requiring robust calibration and adaptive algorithms. Ambient light and vibration on

lines create additional noise.

d) Data labeling and model generalization

Machine-learning approaches need labeled datasets that cover the diversity of defect

appearances and production conditions. Gathering large, balanced datasets for rare defects like

pinholes is challenging; synthetic augmentation and transfer learning are strategies used in

research.

## 2.6 Gaps identified in the literature & promising directions

From the sources reviewed, the following gaps and research opportunities are apparent:

I) Limited open datasets for pinhole detection — many vendors claim lack

independent published datasets or benchmarks. Public datasets would accelerate

algorithmic research.

II) Hybrid multi-sensor fusion — while combinations of backlight and reflective imaging are used in industry, academic literature on optimal sensor fusion

architectures for blown film (balancing cost, speed and detection performance)

is limited.

III) Real-time ML deployment on constrained hardware — more work is needed on

deploying accurate ML classifiers on low-latency embedded hardware or FPGA

systems tailored to line-speed constraints.

IV) | Robustness to metallized films and opaque layers — specialized
illumination/spectral | strategies | for | metallized | films | need | broader

documentation and comparative studies.

## 2.7 Recommendations for designing a vision-based pinhole detection system for blown film lines

Based on the literature and industrial practice, the following recommendations are supported:

a) Primary modality: transmission/backlight imaging — implement a high-uniformity

backlight across the full web width with low-noise, high-dynamic range sensors for

primary pinhole detection. Use narrowband LEDs if spectral tuning helps contrast.

b) Dual modality — add a reflective camera bank for surface defects (gels, scratches)

so a single inspection station detects both pinholes and surface anomalies.

c) Two-stage processing pipeline — stage 1: fast thresholding and morphological

filtering on FPGA/edge device to detect candidates; stage 2: ML classifier (CNN)

to reduce false positives and classify defect types. Use temporal voting across

frames for transient noise rejection.

d) Calibration, adaptive thresholds and logging — implement routine flat-field

calibration, auto-gain control, and per-run baseline learning to accommodate

material variability. Provide full logging and visualization so operators can review

candidate defects and perform root-cause analysis.

e) Preventative measures — pair detection with process control and preventative

maintenance: melt filtration, drying procedures, screen checks, and controlled

winding tension can reduce pinhole incidence. Use detection feedback to flag runs

for process intervention rather than only roll rejection.

f) Validation and acceptance testing — establish test artifacts with calibrated pinhole

sizes (targets) to validate sensitivity claims and set operating thresholds; measure detection performance (precision, recall) and line throughput under production

conditions.

## 2.8 Conclusion

The literature and industry materials converge on transmission/backlight imaging as the

foundation for pinhole detection on blown film lines, often supplemented by low-light sensors

and dedicated photonics modules for very small defects. Traditional image processing

techniques remain useful for initial detection; machine-learning classifiers increasingly help

reduce false positives and extend detection to multiple defect classes. Commercial vendors

provide turnkey solutions, but independent evaluations and open datasets are rare. Designing a

robust vision-based pinhole detector requires careful attention to illumination engineering,

sensor selection, real-time processing architecture, and process integration (prevention +

detection). Future research should prioritize sensor fusion, deployment of ML in constrained

real-time environments, and standardized datasets/benchmarks for pinhole and film defects.

# CHAPTER THREE: METHODOLOGY

## 3.1 INTRODUCTION

This chapter presents the methodology adopted for the design, development, and validation of

a camera-based pinhole detection system for blown film extrusion lines used in food packaging

production. The purpose of this chapter is to describe, in a structured and reproducible manner,

the engineering approach followed to transform the identified industrial problem into a

functional prototype capable of real-time defect detection.

The chapter outlines:

- The research design approach
- Analysis of the blown film extrusion process
- Development of multiple conceptual equipment designs
- Evaluation and selection of the optimal concept
- Hardware and software architecture
- Image acquisition strategy
- Algorithm development
- Experimental validation procedure
- Performance evaluation methods
- Safety considerations and system limitations

The methodology ensures that the system is technically feasible, economically viable, safe for

industrial use, and aligned with food packaging quality requirements. This chapter further

outlines how the proposed system integrates hardware and software components to enable real-

time detection of pinhole defects in polymer film before winding.

### 3.1.2 Overall Methodology Framework

## 3.2 Research Design

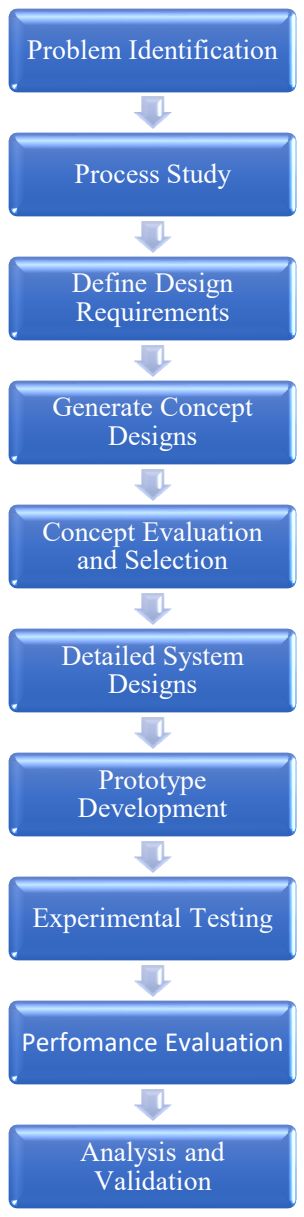
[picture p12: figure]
Problem Identification; Process Study; Define Design Requirements; Generate Concept Designs; Concept Evaluation and Selection; Detailed System Designs; Prototype Development; Experimental Testing; Perfomance Evaluation; Analysis and Validation

This study adopts an applied experimental engineering research design. The goal is not only

theoretical investigation but also the development of a practical working prototype.

### 3.2.1 Nature of the Research

- Applied research
- Experimental validation
- Prototype-based development

- Quantitative system evaluation

The research integrates:

- Mechanical design
- Optical engineering
- Image processing
- Polymer processing knowledge

## 3.3 Description of the Blown Film Extrusion Process

Understanding the extrusion process is critical before inserting an inspection system. Blown

film extrusion consists of polymer melting, bubble formation, cooling, collapsing and winding.

### 3.3.1 Process Flow

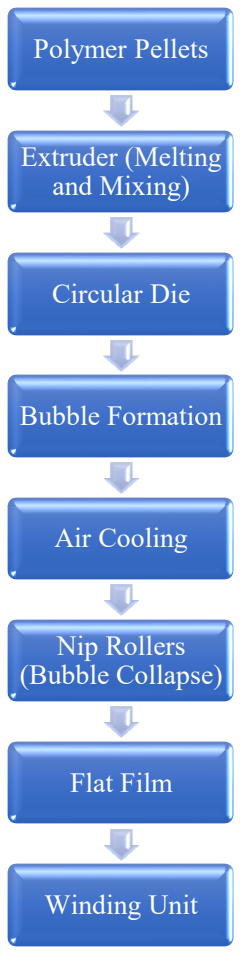
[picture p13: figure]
Polymer Pellets; Extruder (Melting and Mixing); Circular Die; Bubble Formation; Air Cooling; Nip Rollers (Bubble Collapse); Flat Film; Winding Unit

Polymer Pellets

This is the first stage of the process, raw material feeding happens here. Polymer pellets are

small granules of thermoplastic material, commonly Low-Density Polyethylene (LDPE),

Linear Low-Density Polyethylene (LLDPE), High-Density Polyethylene (HDPE) and

Polypropylene (PP). for food packaging, materials must comply with food safety standards.

For this research I will be focussing on packaging material made from LLDPE and LDPE. The

composition of the material I will use as a sample is 80% medium duty LDPE + 20% LLDPE.

The raw materials are poured into a mixer according to the composition ratios mentioned

above, additives such as slip agents, anti-block agents, UV stabilizers and colour masterbatch

may be added and mixed well with the polymer pellets in the mixer. The mixture is passed

through a dryer to remove moisture. The pellets are loaded into a hopper. This stage is

important because if raw materials contain moisture, it will cause bubbles, voids and pinholes,

any present contaminants cause weak spots and film defects and poor mixing will lead to

thickness inconsistency. Defects originating at this stage can cause pinholes later in the film.

Extruder (melting and mixing)

The main components are barrel, rotating screw, heaters and temperature controllers, motor

and gearbox. The barrel has three zones, i.e., feeding zone, compression zone and metering

zone. The screw rotates and works in all three zones.

a) Feeding Zone: pellets enter from the hopper and the material

begins to compact. Friction begins heating the material.

b) Compression Zone: channel depth decreases, polymer begins to

melt and pressure builds up. Air pockets are removed at this

zone.

c) Metering Zone: the polymer is now fully molten, it has uniform

temperature, stable pressure and steady flow toward the die.

The critical parameters are barrel temperature, screw speed, pressure stability and melt

homogeneity. These matter because if temperature is too low there will be incomplete melting

which causes gel defects, if the temperature is too high, the polymer degrades and pressure

fluctuations cause thickness variation. All these can cause weak film areas and pinholes.

Circular die

Before the melt reaches the die, it passes through fine mesh screens where contaminants are

filtered out. The melt flow becomes more uniform. The importance of this is that it removes

un-melted particles, removes dirt or degraded polymer and prevents die blockage. Without filtration foreign particles can cause micro-tears, weak film zones and pinhole formation. The

film is formed at this stage; the molten polymer becomes a tube. The circular die distributes

molten polymer evenly around a ring. The polymer melt exists as a thin tubular shape. Wall

thickness is controlled by die gap, melt pressure and flow uniformity. The critical die design

factors are die gap precision, flow channel symmetry and temperature uniformity. The die is

the common point of origin for pinholes. Other possible defects at the die are uneven flow

which leads to thickness variation, die lip damage which causes streaks and poor pressure

control which leads to weak spots.

Bubble formation

Air is introduced inside the tube. The internal air pressure inflates the tube; film diameter

increases and stretching occurs in machine direction (MD) and transverse direction (TD). This

improves mechanical properties. If air pressure fluctuates, bubble instability occurs, if

stretching is uneven, it forms weak zones and over-stretching leads to thinning and causes

pinholes. Blow up ratio is critical at this point; it is given by the formula BUR =

bubble diameter
die diameter
Air cooling

The air ring is responsible for cooling the bubble immediately after exiting the die. Air is blown

around the bubble, polymer cools and solidifies and film becomes stable. The key parameters

are air temperature, air velocity and uniform distribution. Problems that may arise are if uneven

cooling happens there is thickness variation, presence of turbulence causes bubble instability

and poor cooling will result in a weak film structure. Uneven crystallization reduces

mechanical strength.

Nip rollers

Before the tube reaches the collapsing frame there is a frost line, where the film becomes fully

solid. The polymer transitions from molten to solid and molecular orientation is locked in. if

the frost line is too high there is slow cooling, if it is too low there is rapid cooling stress and

inconsistent frost line cause mechanical weakness. The collapsing frame is where the bubble

flattens. It is guided into a flat sheet. Guides and frames collapse the tube, air inside is removed

and tube becomes a double-layer flat film. The risks are misalignment and it causes wrinkles,

excess tension causes tearing and mechanical stress causes micro-cracks. The nip rollers pull

film upwards, maintain tension and control film thickness. Film thickness depends on screw

speed, nip speed and air pressure. If nip speed increases the film becomes thinner. There is an

increased risk of pinholes if the film is too thin.

Flat film

There is a flat film after the nip rollers, this is where the detection system will be integrated.

This position is ideal because film fully solid, film is flat, there is no bubble distortion and the

surface is stable for imaging. This proves it is the most reliable inspection point.

Winding unit

This is the final stage. Film tension is controlled, roll diameter increases gradually and the

finished product is prepared for use. If defects are not detected before winding, entire roll

becomes scrap, the cost increases and food safety risk increases.

### 3.3.2 Why inspect after nip rollers?

The inspection zone is placed after the nip rollers and before winding because:

- Film is flat and tensioned
- Minimal vibration
- Stable geometry
- Constant thickness
- Easy access for mounting camera and LED
- Does not interfere with bubble stability

This ensures reliable image capture.

## 3.4 Design Requirements

This section is about the requirements of the project, functional requirements, technical

requirements and economic requirements. Functional requirements refer to what the system

must do. These define the core purpose and operational capabilities of the system. Technical

requirements refer to the engineering specifications necessary to achieve the functional

requirements. They define how the system must be built in terms of hardware, software and

performance capability. Economic requirements refer to the cost and financial constraints

under which the system must operate. These ensure that the system is practical and viable for

industrial implementation.

### 3.4.1 Functional Requirements

i. Real-Time Defect Detection

The system must detect pinholes while the film is moving during production, without

stopping the extrusion process. This is important because stopping production increases

downtime and real-time detection prevents defective rolls from being fully wound. This

means, the camera must capture continuous images, the algorithm must process frames

instantly, alerts must be immediate.

ii. | Detection of Minimum Defect Size
| The system must detect pinholes equal to or larger than a specified threshold (e.g., 100
| µm), because very small pinholes can compromise barrier properties and food
| packaging safety depends on integrity. This requirement determines camera resolution,
| pixel-to-micron calibration and algorithm sensitivity.
iii. | Non-Contact Operation
| The system must not physically touch the film because contact can damage thin film, it
| may introduce contamination and it may interfere with film tension. Therefore, optical
| detection is required and no mechanical probes.
iv. | Continuous Monitoring
| The system must operate continuously during extrusion. This requires stable power
| supply, reliable lighting, robust software and automatic restart capability if errors occur.
v. Automatic Alert System
| When a defect is detected, the system must trigger a visual or audible alarm, log the
| defect data and optionally mark the defective region. This ensures operator awareness,
| immediate corrective action and quality documentation.
vi. | Data Logging and Traceability
| The system must record time of defect, location on film, size of defect and image of
| defect. This supports HACCP compliance, quality audits and process improvement.

### 3.4.2 Technical Requirements

1. Camera Resolution

To detect a 100 µm defect each pixel represents a small enough physical dimension, resolution

≥ 5 MP is recommended and pixel-to-length calibration is required. If resolution is too low

small defects will not be detected.

2. Frame Rate

The camera frame rate must match extrusion speed. If line speed = 60 m/min, camera must

capture enough frames to avoid missing defects. The recommended frame rate is ≥ 60 fps. If

there is low frame rate some defects will be missed.

3. Exposure Time

Exposure must be short to prevent motion blur. If film moves quickly an exposure of < 1ms is

preferred. If there is a blur it reduces detection accuracy.

4. Uniform Illumination

Lighting must be uniform across film width, have stable intensity, be flicker-free. Uneven

lighting causes false positives and incorrect thresholding

5. Processing Speed

The image processing system must analyse each frame within milliseconds, operate without

lag. Processing time per frame should be < 50ms for real-time performance.

6. Mechanical Stability

Mounting structure must minimize vibration, maintain fixed focal distance and be adjustable.

Vibration leads to image distortion.

7. Software Requirements

The system must include image acquisition module, pre-processing filters, thresholding

algorithm, blob detection, measurement algorithm, decision logic, data storage module and the

software must be robust and repeatable.

8. Calibration Requirement

The system must include physical calibration grid, pixel-to-millimetre conversion, periodic

recalibration capability. Without calibration the measurements will be meaningless.

### 3.4.3 Economic Requirements

1. Affordable Initial Cost

The system should use commercial industrial camera (not research-grade ultra-expensive

systems), standard LED panels and PC-based processing. The goal is to keep the total prototype

cost reasonable for local industry.

2. Low Maintenance Cost

The system should use long-life LED lighting, avoid complex mechanical components and use

software-based detection rather than mechanical sensors. This reduces long-term expenses.

3. Energy Efficiency

LED lighting must consume low power, produce minimal heat and operate continuously

without overheating, energy efficiency reduces operational cost.

4. Scalability

The design should be easily upgraded, allow higher resolution cameras if needed and support

future automation integration, this will increase industrial attractiveness.

5. Return on Investment (ROI)

The system should reduce material waste, prevent defective roll production, improve food

safety compliance and reduce product recalls

The economy will benefit comes from reduced scrap, reduced rework, reduced food

contamination risk and improved brand trust. These economic requirements ensure system is

affordable, maintenance is manageable, energy cost is low, industrial adoption is realistic and

long-term savings justify investment.

## 3.5 Conceptual Design Development

### 3.5.1 Introduction

The conceptual design development phase involves the generation, evaluation and selection of

feasible design solutions that meet the identified system requirements. At this stage, abstract

ideas are transformed into structured design concepts through systematic analysis, comparison

of alternatives and consideration of technical, economic and operational constraints.

For the purposed vision-based pinhole detection system for blown film extrusion lines, this

phase focuses on identifying suitable sensing methods, imaging configurations, illumination

techniques, data processing algorithms and system integration strategies. Multiple design

concepts are developed and assessed based on criteria such as detection accuracy, real-time

performance, cost effectiveness, ease of implementation and compatibility with existing

extrusion equipment.

Risk assessment is also conducted to identify potential technical limitations, including motion

blur at high line speeds, lighting non-uniformity, false positives due to gels or contaminants

and data latency issues. The selected conceptual design therefore represents the most

technically feasible and economically viable configuration, forming the baseline for detailed

mechanical design, algorithm development, hardware integration and prototype fabrication.

### 3.5.2Components required

MECHANICAL COMPONENTS

d) Structural frame: mild steel tubing, base support legs and

adjustable height slots.

e) Film handling system: rollers (aluminium idler roller, rubber-

coated drive roller, stainless steel shafts and pillow block

bearings), tension mechanism (spring-loaded tension roller)

f) Drive system: speed controller, timing belt, dc geared motor,

flexible shaft coupling

g) Light isolation housing: enclosed inspection chamber, light

baffles to eliminate ambient light, matte black internal panels

VISION AND ELECTRONIC COMPONENTS

a) Camera system: ESPCAM
b) Illumination system: bright light, lamp holder
c) Control system: ESP32
d) Sensors: emergency stop button, limit switches, rotary encoder and IP proximity sensor
e) User interface: push button (start/stop), buzzer, LED indicator, display

SOFTWARE REQUIREMENTS

Thresholding algorithm, real-time defect counting, edge detection, python/C++

### 3.5.3 Conceptual Design

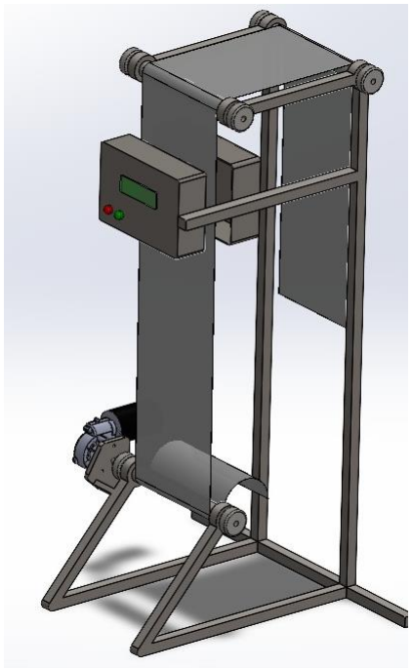
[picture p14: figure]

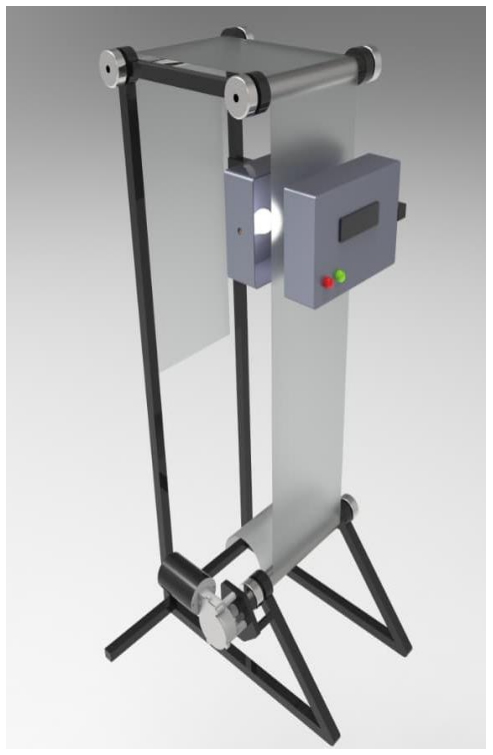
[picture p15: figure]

Working Principle:

The high-intensity LED backlight is placed on one side of the film, while a camera is placed

on the opposite side. The film passes between the light source and the camera during

production. The LED backlight produces a uniform illumination across the film surface,

allowing the camera to capture continuous images of the moving film. If there are no defects,

in this case pinholes, the polymer film partially blocks and diffuses the light, so the camera

records a uniform grey image. When a pinhole defect is present the film is missing at that point.

As a result, more light passes through the hole without being absorbed or scattered by the

polymer. Therefore, the light does not get blocked by the pinhole, light passes through the hole

more easily and the pinhole appears as a bright or lighter spot in the captured image.

The image processing algorithm then analyses the image by thresholding and defect detection

techniques. Regions that are significantly brighter than the surrounding film are identified as

potential pinhole defects. The system can then measure the size and location of the defect and

trigger an alarm if the defect exceeds acceptable limit.

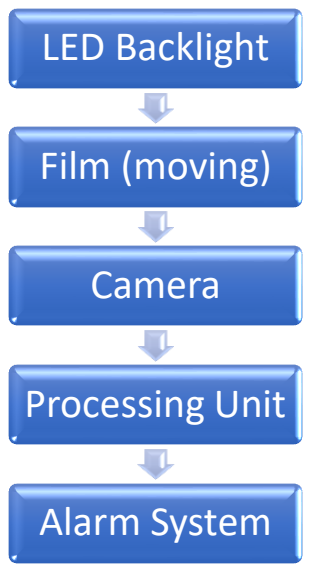
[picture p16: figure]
LED Backlight; Film (moving); Camera; Processing Unit; Alarm System

### 3.5.4 Final System Architecture

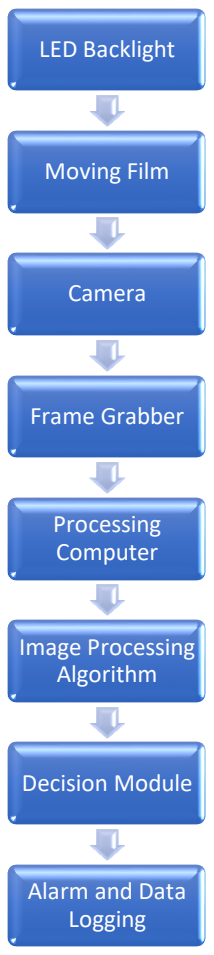
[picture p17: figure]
LED Backlight; Moving Film; Camera; Frame Grabber; Processing Computer; Image Processing Algorithm; Decision Module; Alarm and Data Logging

## 3.8 Hardware Implementation

Step 1: Mounting Structure
- Use aluminium frame
- Adjust brackets
- Anti-vibration mounts
Step 2: LED Installation
- Mount LED panel behind film
- Ensure uniform brightness
- Connect to stable power supply
Step 3: Camera Installation
- Align perpendicular to film
- Fix focal distance
- Adjust exposure
Step 4: Connect to Computer
- Use USB 3.0
- Install camera drivers

## 3.9 Image Acquisition Method

The key settings are:

Exposure time<1ms (avoid blur)

Fixed aperture

Constant lighting

Frame rate matched to line speed

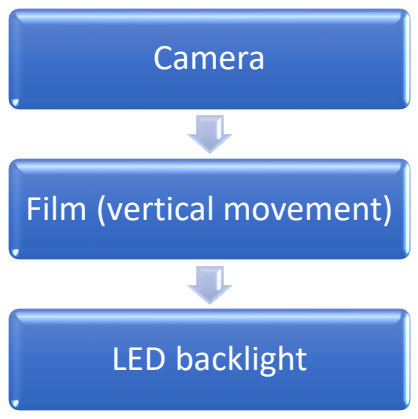
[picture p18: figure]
Camera; Film (vertical movement); LED backlight

## 3.10 Image Processing Algorithm

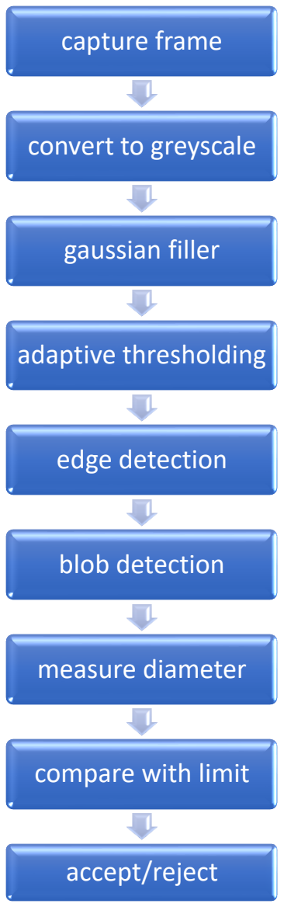
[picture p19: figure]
capture frame; convert to greyscale; gaussian filler; adaptive thresholding; edge detection; blob detection; measure diameter; compare with limit; accept/reject

Mathematical Equations

Thresholding:
T(x, y) = 1 if I(x, y) < λ

T(x, y) = 0 otℎerwise

Equivalent diameter:
d = 2√
Area
π

If D ≥ 100μm , defect detected

## 3.11 Experimental Procedure

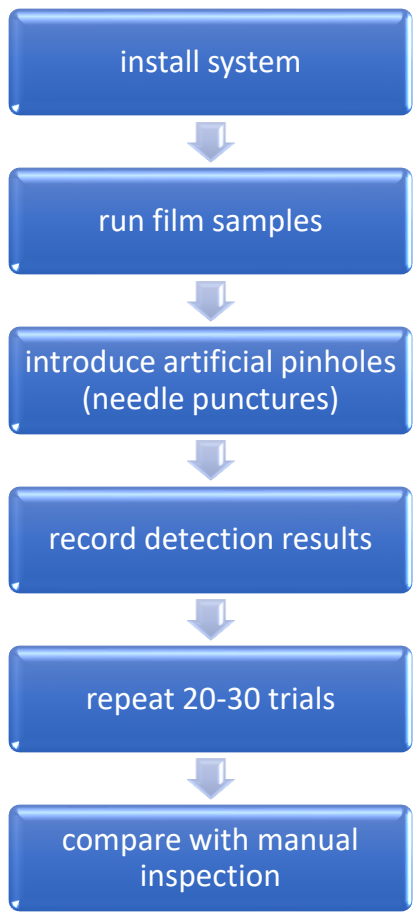
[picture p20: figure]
install system; run film samples; introduce artificial pinholes (needle punctures); record detection results; repeat 20-30 trials; compare with manual inspection

## 3.12 Performance Evaluation

The performance of the system will be evaluated by testing the system using film samples

containing artificial and naturally occurring pinhole defects. The evaluation will focus on the

detection accuracy, detection speed and reliability of the system during continuous film

movement. Parameters to evaluate include false detection rate, minimum detectable pinhole

size, system response time, inspection coverage and detection accuracy.

The metrics that I will use are

1. Accuracy

accuracy =

(TP + TN)
total observations

Where TP is true positives and TN is true negatives

2. Sensitivity

sensitivity =

TP
(TP + FN)

Where FN is false negative

3. False positive rate

FPR =

FP
(FP + TN)

Where FP is false positive

4. Processing time

Time per frame required is <50ms

## 3.13 Data Analysis

The captured data will be analyzed using statistical and image analysis techniques. Detected

defects will be compared with manually measured pinhole sizes to determine detection

accuracy. The results will be summarized using tables, graphs and statistical metrics such as

detection rate and error percentage.

1. I will tabulate the results
2. Using the table I will the graph of detection rate vs defect

size

3. I will compare manual inspection and automated inspection
4. I will calculate the mean and standard deviation

## 3.14 Safety Considerations

- Insulated wiring
- Secure mounting
- No interference with rollers
- Eye safety for LED

# RERERENCES

1. Abeykoon, C., et al., 2022. Sensing technologies for process monitoring in polymer

extrusion. Sensors & Actuators (ScienceDirect). (Review; discusses state-of-the-art

process monitoring and sensors).

2. Rawashdeh, N., 2023. Vision-based Online Defect Detection of Polymeric Film via

Structural Quality Metrics. (Michigan Tech / conference paper). Demonstrates online

vision metrics for extrusion-blown HDPE film.

3. Hamamatsu Photonics, 2020. Optical Pinhole Inspection Unit (product bulletin and technical note). Hamamatsu News & product pages (C12570 / C15477) — describes

photonic pinhole units and detection sensitivity claims.

4. Antares Vision Group. Pinhole Detector product page. (product description for

backlight pinhole detectors used in packaging).

5. Erhardt+Leimer, 2020. SMARTSCAN: Pinhole detection for converting industry.

Product news describing 200% inspection with pinhole detection.

6. LydenellBasell, 2015 (technical brochure). How to solve blown film problems.

(Technical notes on defect types, causes and troubleshooting).

7. Johnson, J., et al., (paper). Defect and thickness inspection system for cast thin films

using machine vision and full-field transmission densitometry. (Discusses densitometry

and machine vision for film inspection).

8. ResearchGate / thermography ANN study: Detection of pinhole defects in optical film

using thermography and artificial neural network. (Research article demonstrating

thermography approaches).

9. Manufacturer & industry sources on common blown film causes (Plasco, EUPEgypt

troubleshooting articles), summarizing causes like contaminants, temperature issues

and screen damage.

10. Trident Products blog / industry case: Extruded Film Inspection System sharpens defect

detection. (Industry report on vision systems applied to extruded film and composite

monitoring).

11. Patent: Pinhole-resistant extrusion method — US6228201B1 (patent discussing volatile

entrainment and pinhole formation mechanisms).

12. Cabuk FAQ / technical note: Cause of Pinholes (industry note summarizing pinhole

mechanisms and prevention).

13. Miyahara Rubber technical note: Pinholes: main causes and prevention. (Practical

guidance on roots and prevention).

14. Jornen product page: Pinhole detector for blister packaging lines. (Commercial product

overview targeting blister/forming lines).

15. ACG / QUALISHIELD and ACG-world blister/pinhole inspection product pages.
16. Scanware / Patera Focon: Packaging Inspection and pinhole inspection units (industrial

product notes).

17. University and thesis resources on in-line extrusion monitoring and product quality

(Alavi, 2010; other academic documents on extrusion defects).

18. Cantor, K. (2019). Blown Film Extrusion. 3rd ed. Munich: Hanser Publishers.
19. Giles, H. F., Wagner, J. R. and Mount, E. M. (2013). Extrusion: The Definitive

Processing Guide and Handbook. 2nd ed. Oxford: Elsevier.

20. Rolbatch Academy (2022). Blown Film Extrusion – Process Optimization and

Troubleshooting.

21. Harper, C. A. (2006). Handbook of Plastics Technologies. New York: McGraw-Hill.
22. Strong, A. B. (2006). Plastics: Materials and Processing. 3rd ed. Upper Saddle River:

Pearson.

23. Gonzalez, R. C. and Woods, R. E. (2018). Digital Image Processing. 4th ed. Pearson.
24. Szeliski, R. (2010). Computer Vision: Algorithms and Applications. Springer.
25. Bradski, G. and Kaehler, A. (2008). Learning OpenCV: Computer Vision with the

OpenCV Library. O’Reilly Media.

26. Raps, D., Hosseinabadi, H., Heymann, L. and Altstädt, V. (2018). Rheological

properties of thermoplastic polymers with dissolved gases for foaming applications.

arXiv.

27. Toukhtarian, R. G. (2019). Modeling and simulation for varying die gap fluid extrusion.

arXiv.

28. Mortimore, S. and Wallace, C. (2013). HACCP: A Practical Approach. 3rd ed.

Springer.

29. Fellows, P. (2009). Food Processing Technology: Principles and Practice. 3rd ed.

Woodhead Publishing.

30. Standards Association of Zimbabwe (SAZ). (2024). Standards information and

certification services. Available at: https://www.saz.org.zw/

31. SAZ (2023). ZWS 749: Requirements for a Hazard Analysis and Critical Control Point

(HACCP) system.

32. SAZ (2009). ZWS ISO 22000: Food Safety Management Systems.
33. SAZ (1997). ZWS 126: Food Hygiene – Manufacturing.
34. ISO (2018). ISO 22000: Food Safety Management Systems – Requirements for any

organization in the food chain.

35. ISO (2022). ISO 9001: Quality Management Systems.
36. ISO (2015). ISO 22005: Traceability in the feed and food chain.
37. Marsh, K. and Bugusu, B. (2007). Food packaging—roles, materials, and

environmental issues. Journal of Food Science, 72(3), pp.39–55.

38. Robertson, G. L. (2016). Food Packaging: Principles and Practice. 3rd ed. CRC Press.
39. Cantor, K., 2019. Blown Film Extrusion. 3rd ed. Munich: Hanser Publishers.
40. Giles, H.F., Wagner, J.R. and Mount, E.M., 2013. Extrusion: The Definitive Processing

Guide and Handbook. Oxford: Elsevier.

41. Gonzalez, R.C. and Woods, R.E., 2018. Digital Image Processing. 4th ed. Pearson.
42. Mortimore, S. and Wallace, C., 2013. HACCP: A Practical Approach. Springer.
43. Standards | Association | of | Zimbabwe | (SAZ), | 2024. | Available | at:

https://www.saz.org.zw/

44. SAZ, 2023. ZWS 749: Requirements for a Hazard Analysis and Critical Control Point

(HACCP) System.

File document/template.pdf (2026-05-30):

SCHOOL OF ENGINEERING AND TECHNOLOGY

DEPARTMENT OF POLYMER TECHNOLOGY AND ENGINEERING

CAPSTONE

DESIGNING AND IMPLEMENTATION OF AN AUTOMATED WEIGHT-VISION

SORTING SYSTEM FOR QUALITY CONTROL IN PLASTIC PREFORM

MANUFACTURING.

BY

TARIRO MUFOKOZANA

H210219E

SUPERVISOR:

ENG. J CHIFAMBA

A HIT400 PROJECT REPORT SUBMITTED IN PARTIAL FULFILMENT OF THE

REQUIREMENTS OF THE BACHELOR OF TECHNOLOGY (HONS) DEGREE OF

POLYMER TECHNOLOGY AND ENGINEERING

2024/2025

COPYRIGHT

Copyright ©2025. All rights reserved.

All rights reserved. No part of this research may be reproduced, stored in any retrieval system, or

transmitted in any form or by any means, electronic, mechanical, photocopying, recording, or

otherwise for purpose without the prior written permission of the author.

i

DECLARATION

## I___________________ registration number _____________ do hereby declare that this

research project is original.

Harare Institute of Technology

Department of polymer technology and engineering

P.O. Box Be277

Belvedere

Harare

Zimbabwe

## STUDENT_____________________________________ DATE __________________

## SUPERVISOR SIGNATURE______________________ DATE __________________

ii

DEDICATION

I dedicate this research paper to God, whose grace and guidance have been the foundation of my

journey, providing strength, wisdom, and perseverance. I also dedicate this research paper to my

parents as a token of appreciation for being my pillars of strength and providing unconditional

love, encouragement, and unwavering support. Finally yet importantly, to my friends, and

mentors I express my heartfelt thanks for their invaluable advice, encouragement, and

inspiration, their guidance has been instrumental in shaping my skills and perspectives.

iii

ACKNOWLEDGEMENTS

I would like to take this opportunity to thank all the people who assisted in shaping and refining

this project. To the Institute I extend my deepest gratitude for the knowledge, resources, and

opportunities that have shaped my academic growth, with special mention to my supervisor Eng.

J Chifamba

iv

ABSTRACT

This project presents the design and implementation of an automated weight-vision sorting

system for quality control in plastic preform manufacturing, focusing on polyethylene

terephthalate (PET) preforms. The system addresses critical defects that compromise product

quality and efficiency, including underweight preforms that pose problems in final product like

leakages, thin side walls leading breakage, short shelf life and deformation during handling they

are caused by machine calibration errors, uneven resin distribution, and inconsistent mould

temperatures which lead to structural weaknesses, increased material waste, and economic

losses. Visual defects such as surface flaws (e.g., black spots, bubbles, flow lines), structural

issues (e.g., cracks, warped bottoms, non-circular finishes), and color optical imperfections (e.g.,

yellowing, dimming) are also targeted, stemming from degraded resin, trapped gases, poor

drying, and contamination. These defects significantly impact the mechanical integrity, aesthetic

appeal, and functionality of the final products, often resulting in higher scrap rates and

production inefficiencies. Addressing these issues at preform level or stage is less expensive than

correcting issues at preform level production the bottle production process it reduces waste,

minimizes rework, and rework, and lowers overall production costs. By integrating weight

measurement with computer vision and machine learning, the system enhances defect detection

accuracy, reduces waste, and aligns with Industry 4.0 principles. Developed using locally

available resources, it offers a cost-effective and scalable solution, particularly beneficial for

industries in developing regions like Zimbabwe, promoting technological advancement,

economic self-reliance, and sustainable manufacturing practices.

v

Table of Contents

vi

vii

viii

ix

x

6.1. Economic analysis | 78
CHAPTER 7 CONCLUSION AND RECOMMEDATIONS | 81
7.1 Conclusion | 81
7.2 Recommendations | 82
REFERENCES | 83
CODES | 85

xi

Table of Figures

xii

CHAPTER 1: INTRODUCTION

### 1.1 Introduction

Plastic preforms are critical building blocks for producing PET bottles, and they require strict adherence

to quality standards so as to guarantee structural strength, precise dimensions and uniformity during the

blow-moulding process. Flaws such as irregular wall thickness, surface defects or material variations can

result in bottle malfunctions, wasted products and safety hazards for consumers. Conventional quality

control approaches in preform production often depend on manual checks or automated systems focused

on a single parameter such as weight measurement, which are vulnerable to human error, inefficiencies

and limited defect coverage. To address these gaps, this study introduces a hybrid automated system

merging load cell-based weight analysis, computer vision inspection which is designed to improve

defect detection by simultaneously identifying physical irregularities, for instance, weight discrepancies

and visible flaws such as cracks and discolouration in real time. By integrating multi-sensor data, the

system enhances sorting precision while aligning with Industry 4.0 objectives of intelligent automation,

data-centric processes, and reduced manufacturing waste.

### 1.2 Background study

Plastic preforms manufacturing demands high precision, as even minor defects can propagate during

blow moulding, leading to costly recalls or production delays. Current quality control practices face

several challenges such as,

- Manual Inspections - are labour-intensive, subjective and slow, with limited scalability for high-

volume production.

- Single-Parameter Systems - Weight-only or vision-only systems fail to detect interrelated

defects for instance a preform with good visual qualities but thin side walls.

- Material Variability - Inconsistent resin distribution or injection moulding parameters can cause

undetected flaws in mass or geometry.

Recent advancements in sensor fusion and machine vision offer opportunities to overcome these

limitations, for instance, computer vision algorithms such as convolutional neural networks can detect

surface defects with high accuracy, while high-precision load cells measure minute weight deviations.

Hybrid systems integrating these technologies have shown promise in industries like food processing

and automotive manufacturing but remain under-explored in plastic preform quality control. This project builds on prior work in multi-sensor quality control systems, adapting them to the unique requirements

of preform manufacturing. By correlating weight and visual data, the system can identify subtle defects

that single-sensor systems might miss, such as preforms with acceptable weight but internal voids or

surface cracks.

### 1.3 Problem Statement

Undetected defects in plastic bottle preforms, such as underweight units, short shots, cracks, and dents,

persist in manual and existing automated inspection systems, causing material waste, structural

weaknesses, and reduced product quality. A more precise and efficient automated system is needed to

overcome these limitations and ensure high-quality production.

### 1.4 Aim

To design and implement an automated weight-vision sorting system that enhances quality control in the

manufacturing of plastic preforms, ensuring that all products meet specified standards so as to minimise

defects, reduce material waste, improve overall production efficiency and product reliability.

### 1.5 Objectives

1. To determine a suitable conveyor system that can be integrated with automated sorting system.
2. To design a system that uses machine vision and load cells to identify preform defects
3. To develop a sorting mechanism that effectively separates items into designated bins.
4. To integrate item detection capabilities that automatically activate the conveyor belt when items are

present.

5. To evaluate the efficiency and performance of the designed system in a controlled environment.

### 1.6 Justification

The | increasing global demand for consistent, defect-free plastic products and the need to enhance
quality control standards | in | manufacturing especially in | fast-paced, high-volume | production

environments such as plastic bottle preform manufacturing. As consumer preferences and regulatory

bodies demand greater precision, traceability, and environmental responsibility, quality assurance has

become a strategic necessity rather than a luxury.

Manual inspections miss 15–20% of defects due to human fatigue and subjective judgment (SPE

Technical Paper, 2023). Standalone weight sensors fail to detect 35% of visual defects cracks, dents and

white foot (ASTM D1999-22: Standard Test Method for Impact Resistance of Plastic Bottles). Defective preforms that pass undetected may lead to product recalls and poor customer perception. Material

Waste: Late-stage defect detection increases scrap rates by 12–15% (SPE Sustainability Report, 2022).

Reprocessing defective preforms costs manufacturers 0.08–0.12/unit (Amcor Case Study, 2021).

### 1.7 Hypothesis

The proposed automated system will improve sorting efficiency by integrating weight sensors

and computer vision. It is expected to reduce sorting errors, enhance processing speed, and

minimize reliance on manual labor.

### 1.8 Scope

The system focuses on sorting PET preforms based on weight and visual inspection. The solution

applies to manufacturing industries dealing with high-volume plastic preforms.

### 1.9 Conclusion

The challenges of plastic preform sorting and the need for an automated system integrating weight

analysis and computer vision. The study aims to enhance defect detection, improve sorting accuracy,

and align with Industry 4.0 standards for smarter manufacturing.

CHAPTER 2: LITERATURE REVIEW

### 2.1 Introduction

Quality control in polyethylene terephthalate (PET) preform manufacturing is vital to ensure the

production of defect-free plastic bottles, as minor flaws at the preform stage can lead to significant

structural and functional issues in the final product. Underweight and overweight preforms, along with

defects such as short shots, white foot, and blemishes, compromise bottle integrity, leading to waste and

safety concerns. This review examines these defects, defines underweight, highlights the essence of the

project, and underscores the importance of the Edge Impulse training model, software, and hardware

mechanisms in defect detection. It also explores the necessity of quality control at the preform level,

preform weights and their corresponding bottle types, existing sorting systems and their limitations, and

the suitability of belt conveyors, cameras, and proximity sensors for an automated weight-vision sorting

system.

Ensuring quality control in plastic preform manufacturing is essential for producing reliable and defect-

free products. Traditional sorting methods, such as manual inspections and single-parameter automated

systems, often fall short, allowing flaws like weight inconsistencies and surface defects to go unnoticed.

These limitations can lead to material waste, compromised structural integrity, and inefficiencies in

production.

### 2.2 Definition of Underweight Preform

A preform is considered underweight if its mass falls below the specified threshold for its intended

bottle size, typically by 5–10% (e.g., below 12 g for a 500 ml bottle). This leads to insufficient material

for proper blow molding, exacerbating defects like thin sidewalls and leakages (Patil & Joshi, 2022).

### 2.3 Importance of Eliminating Defects at Preform Level:

Detecting and removing defective preforms before blow molding prevents downstream issues, such as

product recalls, consumer safety risks, and material waste (estimated at 12–15% scrap rates for

undetected defects) (SPE Sustainability Report, 2022). Early elimination ensures structural integrity,

reduces reprocessing costs (0.08–0.12 USD/unit), and enhances brand reputation by delivering high-

quality bottles (Amcor Case Study, 2021).

### 2.4 Defects Associated with Underweight and Overweight Preforms

Underweight and overweight preforms, along with specific defects like short shots, white foot, and

blemishes, significantly affect the quality of PET bottles. These defects include:

### 2.4.1 Underweight Preforms:

Thin Sidewalls: Insufficient material in underweight preforms results in thin sidewalls during blow

molding, weakening the bottle’s structural integrity and increasing susceptibility to deformation or

bursting, particularly in carbonated beverage bottles (Patil & Joshi, 2022).

Leakages: Thin sidewalls and uneven material distribution cause leakages, compromising the bottle’s

ability to retain contents, leading to product loss and consumer dissatisfaction (Patil & Joshi, 2022).

Cracks: Underweight preforms may develop cracks, particularly at the neck, due to inadequate resin

volume, reducing mechanical strength and compatibility with automated filling systems (Zhao et al.,

2018).

Overweight Preforms:

Excess Material Costs: Overweight preforms, exceeding the target weight (e.g., above 16 g for a 500 ml

bottle), consume excess resin, increasing production costs and environmental impact (Patil & Joshi,

2022).

Bulging and Asymmetry: Excess material leads to uneven heat distribution during blow molding,

causing bulging or asymmetrical shapes that affect bottle stability and aesthetics (Patil & Joshi, 2022).

Short Shots: Incomplete mold filling due to insufficient resin injection results in short shots, where the

preform lacks critical sections, leading to structural weaknesses and failure during blow molding

(Groove, 2016).

White Foot: This defect appears as a cloudy, white base in the preform, often due to improper cooling or

excessive crystallinity, reducing transparency and mechanical strength, which affects consumer appeal

and bottle durability (Ammar et al., 2020).

Blemishes: Surface imperfections, such as black spots (from carbonized material), bubbles (from

trapped gases), or flow lines (from inconsistent injection), compromise aesthetics and functionality,

potentially leading to contamination or weakened structures (Patil & Joshi, 2022).

Quality control at the preform stage is critical to ensure the reliability, safety, and cost-effectiveness of

PET bottles.

Key reasons include:

-Preventing Downstream Defects: Identifying defects like underweight, overweight, short shots, white

foot, and blemishes at the preform level prevents propagation during blow molding, avoiding costly

recalls and production delays (SPE Technical Paper, 2023).

-Cost and Material Savings: Early detection reduces scrap rates by 12–15% and reprocessing costs,

optimizing resin usage and lowering environmental impact (SPE Sustainability Report, 2022).

- Consumer Safety and Brand Reputation: Defective preforms can lead to leakages or structural failures,

posing safety risks and damaging consumer trust. Rigorous quality control ensures compliance with

regulatory standards (ASTM D1999-22).

- Production Efficiency: Automated quality control enhances throughput in high-volume production,

aligning with modern manufacturing demands for precision and traceability (Kagermann et al., 2013).
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

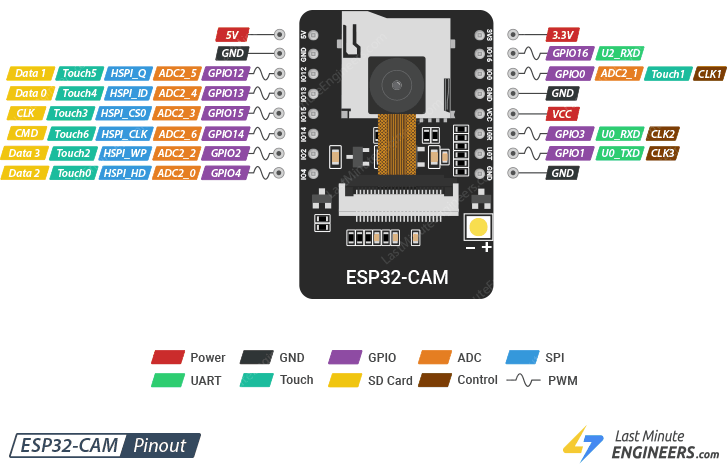
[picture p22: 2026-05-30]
electronics/ESP32-CAM-Pinout.png

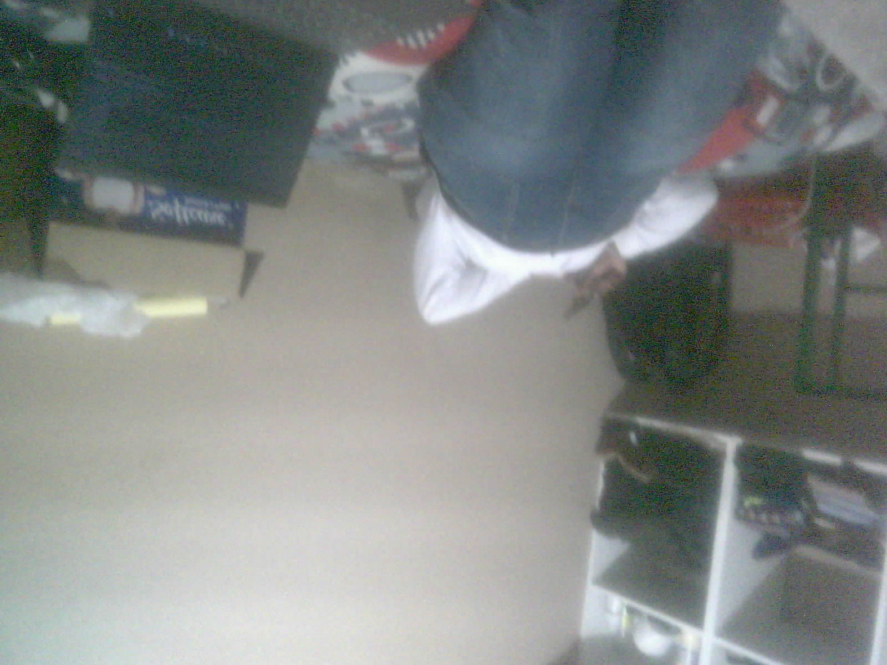
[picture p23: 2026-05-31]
media/captures/2026/05/30/esp32cam_20260530_202317_040772.jpg

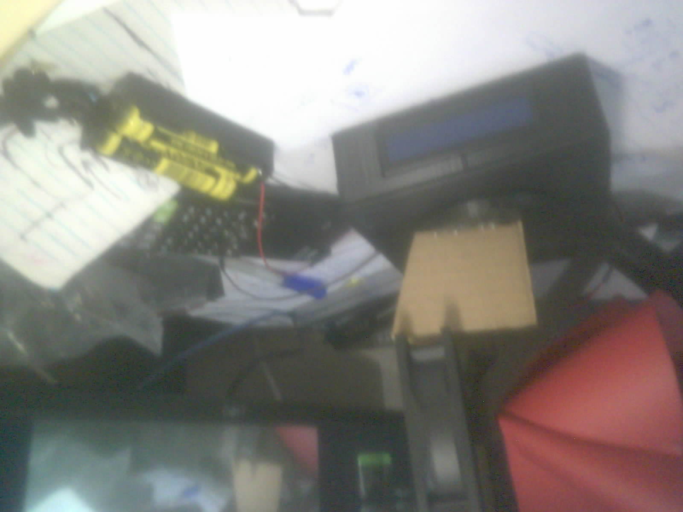
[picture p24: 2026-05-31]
media/captures/2026/05/30/esp32cam_20260530_202148_973238.jpg

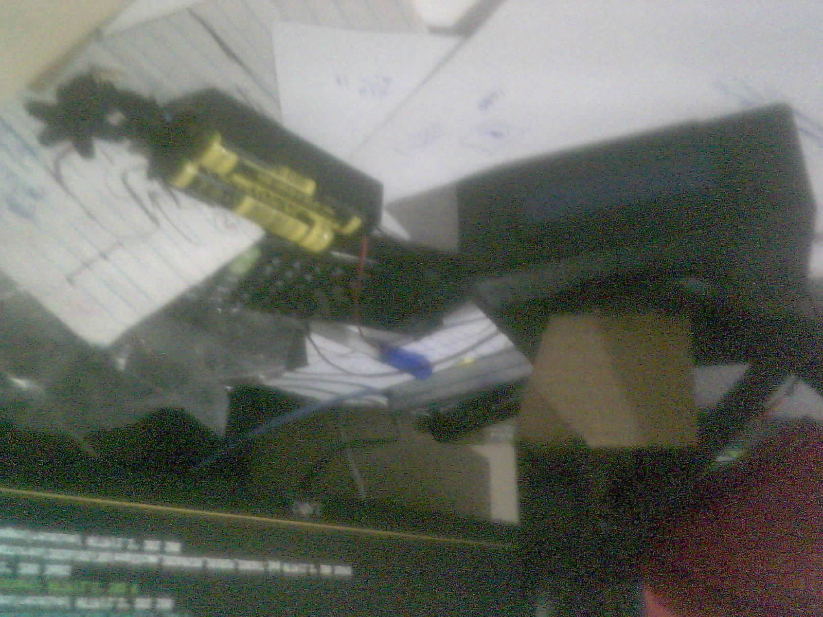
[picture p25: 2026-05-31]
media/captures/2026/05/30/esp32cam_20260530_202007_666486.jpg

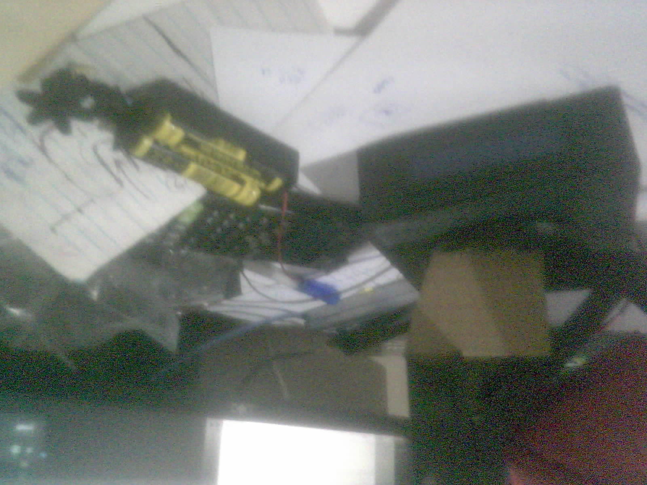
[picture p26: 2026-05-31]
media/captures/2026/05/30/esp32cam_20260530_202115_438023.jpg

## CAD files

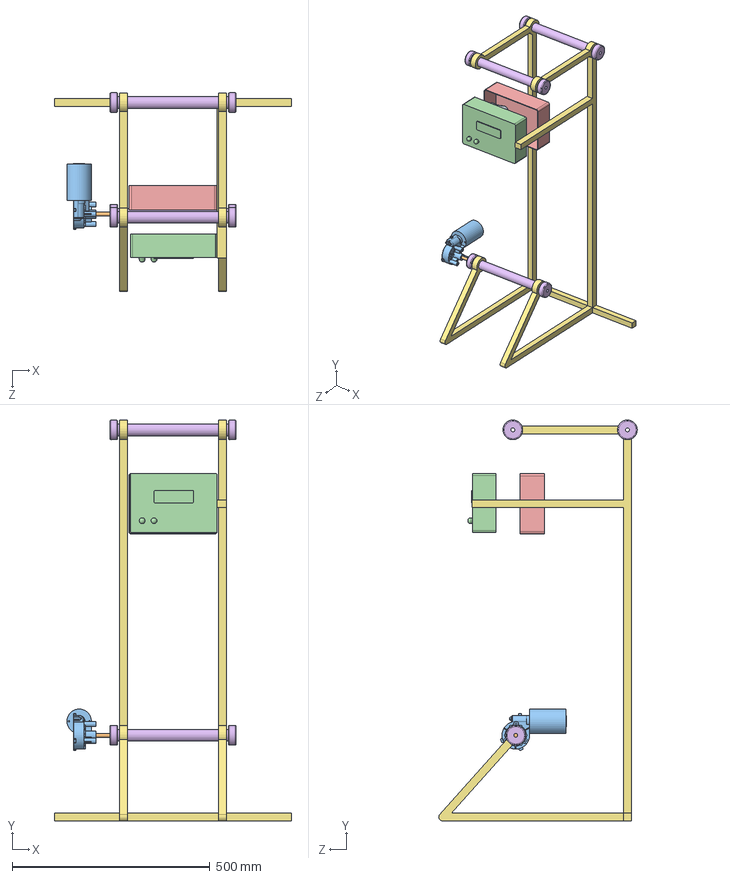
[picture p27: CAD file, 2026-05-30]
3D Model/main.SLDASM
600.0 x 1015.0 x 502.6 mm
structure
roller x 3
light_casing
Front_Device
motor
motor_rod
light

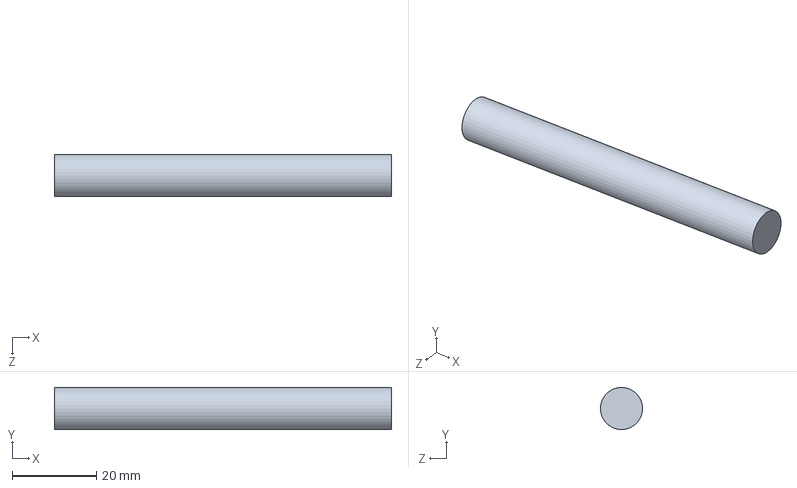
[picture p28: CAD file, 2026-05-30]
3D Model/motor_rod.SLDPRT
80.0 x 10.0 x 10.0 mm

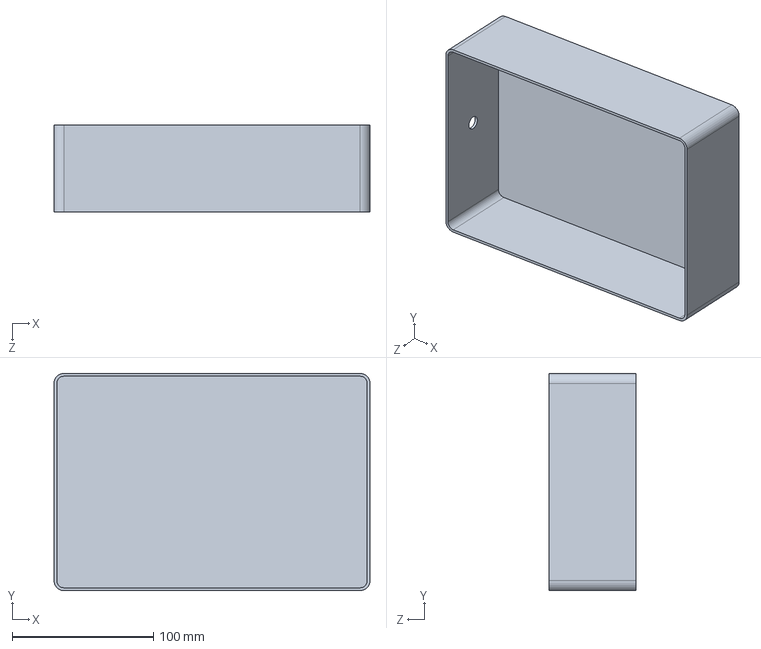
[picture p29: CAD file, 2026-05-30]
3D Model/light_casing.SLDPRT
224.0 x 154.0 x 62.0 mm

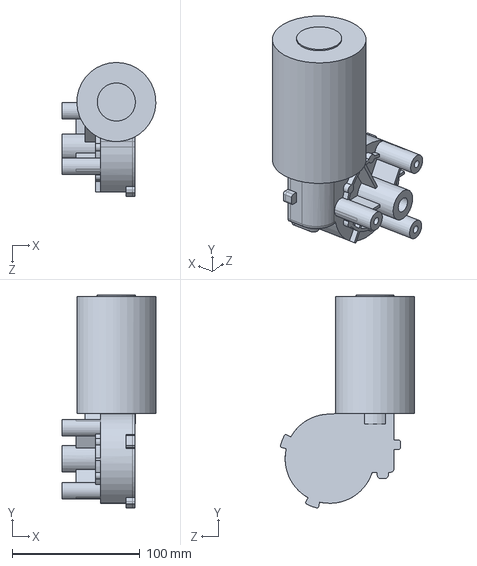
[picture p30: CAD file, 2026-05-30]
3D Model/motor.SLDPRT
73.5 x 167.0 x 105.1 mm

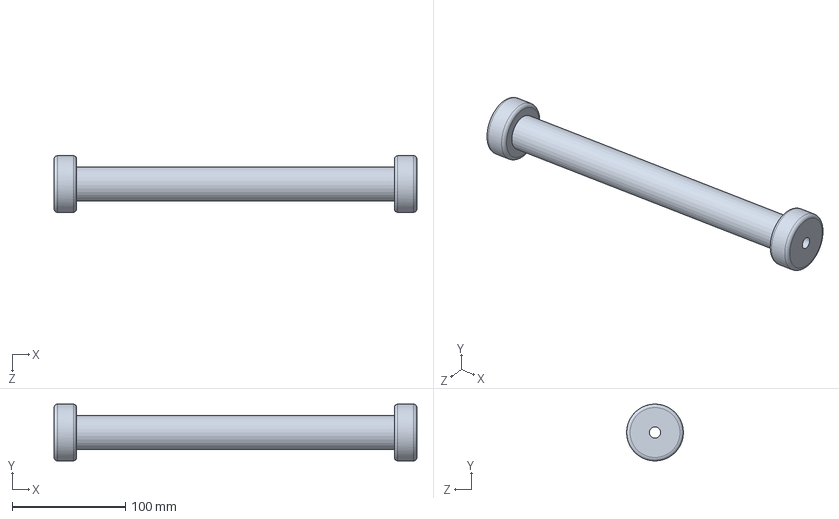
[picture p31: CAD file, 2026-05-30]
3D Model/roller.SLDPRT
320.0 x 50.0 x 50.0 mm

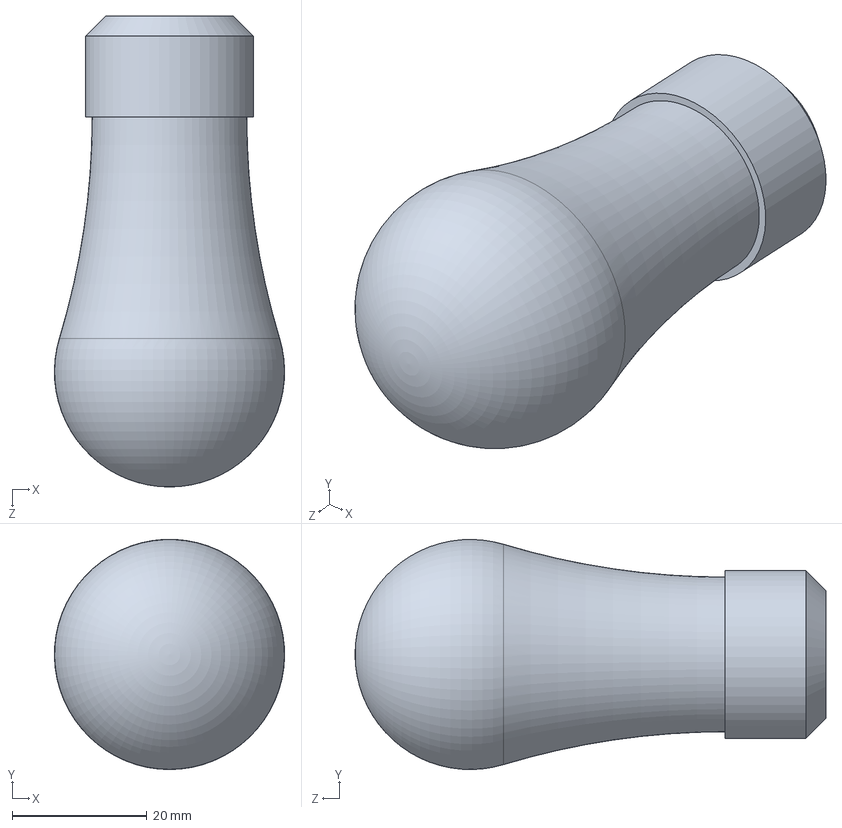
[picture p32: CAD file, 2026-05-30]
3D Model/light.SLDPRT
34.2 x 34.2 x 70.0 mm

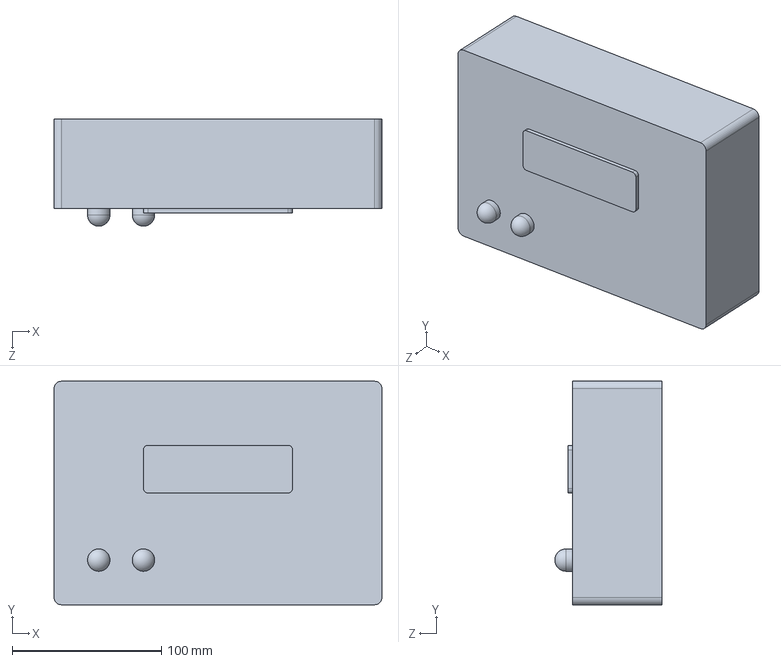
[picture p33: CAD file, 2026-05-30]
3D Model/Front_Device.SLDPRT
220.0 x 150.0 x 72.0 mm

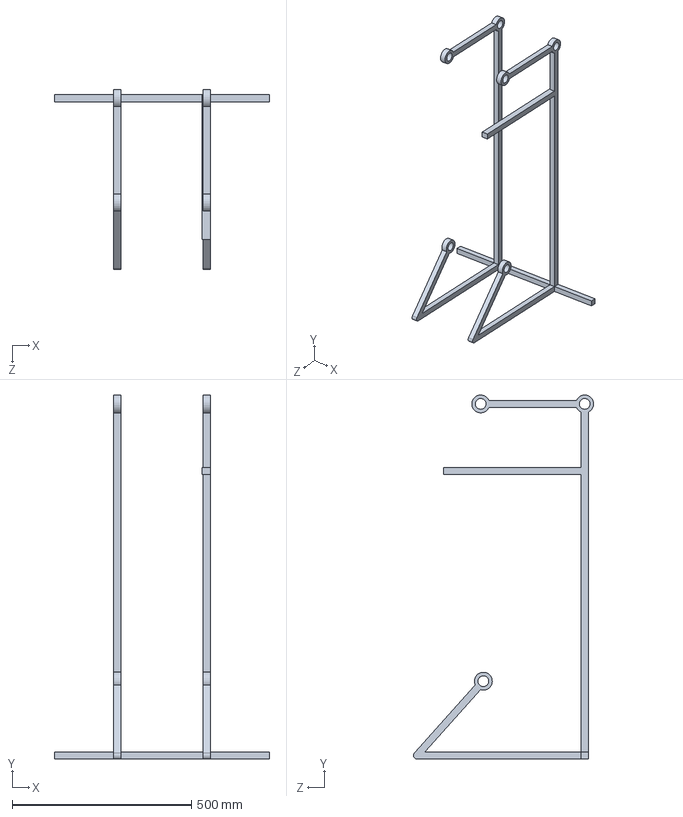
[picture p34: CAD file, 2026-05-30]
3D Model/structure.SLDPRT
600.0 x 1014.8 x 502.4 mm

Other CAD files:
3D Model/plastic.SLDPRT

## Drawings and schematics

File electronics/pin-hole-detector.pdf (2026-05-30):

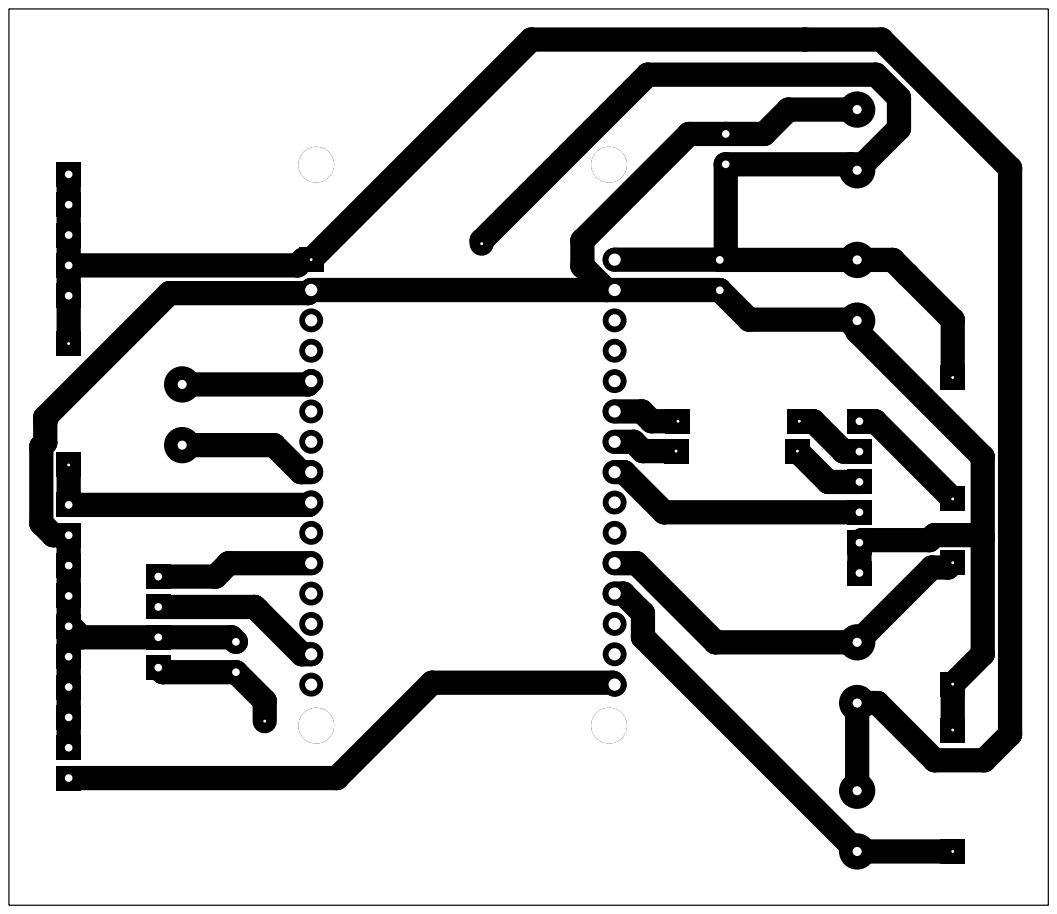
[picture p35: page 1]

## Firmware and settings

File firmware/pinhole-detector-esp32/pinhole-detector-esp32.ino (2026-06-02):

#include <WiFi.h>
#include <PubSubClient.h>
#include <Wire.h>
#include <LiquidCrystal_I2C.h>

// Pin definitions
#define PIN_LIGHT_RELAY     4
#define PIN_MOTOR           5
#define PIN_BUTTON          18
#define PIN_BUZZER          25
#define PIN_LED_STOP        26
#define PIN_LED_START       27
#define PIN_LDR1            34
#define PIN_LDR2            35

// WiFi settings
const char* wifiSsid = "pinhole-detector";
const char* wifiPassword = "pinhole123";

// MQTT settings (same broker as ESP32-CAM)
const char* mqttServer = "192.168.131.85";
const int mqttPort = 1883;
const char* mqttClientId = "pinhole-esp32";
const char* topicState = "pinhole/state";
const char* topicPinhole = "pinhole/detected";
const char* topicControl = "pinhole/control";

// Objects
WiFiClient wifiClient;
PubSubClient mqttClient(wifiClient);
LiquidCrystal_I2C lcd(0x27, 20, 4);

// State variables
bool systemRunning = false;
bool buttonPressed = false;
unsigned long lastDebounceTime = 0;
const unsigned long debounceDelay = 200;

// LDR variables
int ambientLight = 0;
bool ambientRecorded = false;
const int PINHOLE_THRESHOLD = 50;
unsigned long lastLdrRead = 0;
const unsigned long ldrInterval = 100;

// Buzzer timing
unsigned long buzzerStartTime = 0;
bool buzzerActive = false;
const unsigned long buzzerDuration = 2000;


void setup() {
  Serial.begin(115200);
  delay(1000);
  Serial.println("[BOOT] ESP32 Pinhole Detector starting");

  // Pin setup
  pinMode(PIN_LIGHT_RELAY, OUTPUT);
  pinMode(PIN_MOTOR, OUTPUT);
  pinMode(PIN_BUTTON, INPUT_PULLUP);
  pinMode(PIN_BUZZER, OUTPUT);
  pinMode(PIN_LED_STOP, OUTPUT);
  pinMode(PIN_LED_START, OUTPUT);
  pinMode(PIN_LDR1, INPUT);
  pinMode(PIN_LDR2, INPUT);

  // Initial states
  digitalWrite(PIN_LIGHT_RELAY, LOW);
  digitalWrite(PIN_MOTOR, LOW);
  digitalWrite(PIN_BUZZER, LOW);
  digitalWrite(PIN_LED_STOP, HIGH);
  digitalWrite(PIN_LED_START, LOW);

  // LCD setup
  Wire.begin(21, 22);
  lcd.init();
  lcd.backlight();
  lcd.setCursor(0, 0);
  lcd.print("Pinhole Detector");
  lcd.setCursor(0, 1);
  lcd.print("System: STOPPED");

  // Connect WiFi
  connectWiFi();

  // Connect MQTT
  connectMqtt();

  Serial.println("[BOOT] Setup complete");
}

void loop() {
  // Check WiFi
  if (WiFi.status() != WL_CONNECTED) {
    Serial.println("[WIFI] Reconnecting...");
    connectWiFi();
  }

  // Check MQTT
  if (!mqttClient.connected()) {
    Serial.println("[MQTT] Reconnecting...");
    updateLcdLine(3, "MQTT: Reconnecting..");
    connectMqtt();
  }
  mqttClient.loop();

  // Handle button press (active low, debounced)
  handleButton();

  // Handle buzzer timeout
  if (buzzerActive && (millis() - buzzerStartTime >= buzzerDuration)) {
    digitalWrite(PIN_BUZZER, LOW);
    buzzerActive = false;
    Serial.println("[BUZZER] Timeout - stopped");
  }

  // System running logic
  if (systemRunning) {
    // Read LDRs periodically
    if (millis() - lastLdrRead >= ldrInterval) {
      lastLdrRead = millis();
      checkPinhole();
    }
  }
}

void connectWiFi() {
  Serial.print("[WIFI] Connecting to ");
  Serial.println(wifiSsid);

  WiFi.mode(WIFI_STA);
  WiFi.begin(wifiSsid, wifiPassword);

  int attempts = 0;
  while (WiFi.status() != WL_CONNECTED && attempts < 30) {
    Serial.print(".");
    delay(500);
    attempts++;
  }

  if (WiFi.status() == WL_CONNECTED) {
    Serial.println();
    Serial.print("[WIFI] Connected, IP: ");
    Serial.println(WiFi.localIP());
    updateLcdLine(2, "WiFi: Connected");
  } else {
    Serial.println();
    Serial.println("[WIFI] Connection failed");
    updateLcdLine(2, "WiFi: Failed");
  }
}

void connectMqtt() {
  mqttClient.setServer(mqttServer, mqttPort);
  mqttClient.setCallback(mqttCallback);

  while (!mqttClient.connected()) {
    Serial.print("[MQTT] Connecting to ");
    Serial.print(mqttServer);
    Serial.print(":");
    Serial.println(mqttPort);
    updateLcdLine(3, "MQTT: Connecting....");

    if (mqttClient.connect(mqttClientId)) {
      Serial.println("[MQTT] Connected");
      mqttClient.subscribe(topicControl);
      Serial.print("[MQTT] Subscribed to ");
      Serial.println(topicControl);
      updateLcdLine(3, "MQTT: Connected     ");
      publishState();
    } else {
      Serial.print("[MQTT] Failed, state=");
      Serial.println(mqttClient.state());
      updateLcdLine(3, "MQTT: Failed-retry..");
      delay(2000);
    }
  }
}

void mqttCallback(char* topic, byte* payload, unsigned int length) {
  String message;
  for (unsigned int i = 0; i < length; i++) {
    message += (char)payload[i];
  }
  message.trim();
  message.toLowerCase();

  Serial.print("[MQTT] Message on ");
  Serial.print(topic);
  Serial.print(": ");
  Serial.println(message);

  if (message == "start") {
    startSystem();
  } else if (message == "stop") {
    stopSystem();
  }
}

void handleButton() {
  int buttonState = digitalRead(PIN_BUTTON);

  if (buttonState == LOW && !buttonPressed) {
    if (millis() - lastDebounceTime > debounceDelay) {
      buttonPressed = true;
      lastDebounceTime = millis();

      Serial.println("[BUTTON] Pressed - toggling state");

      if (systemRunning) {
        stopSystem();
      } else {
        startSystem();
      }
    }
  } else if (buttonState == HIGH) {
    buttonPressed = false;
  }
}

void startSystem() {
  systemRunning = true;
  ambientRecorded = false;

  // Turn on outputs
  digitalWrite(PIN_LIGHT_RELAY, HIGH);
  digitalWrite(PIN_MOTOR, HIGH);
  digitalWrite(PIN_LED_START, HIGH);
  digitalWrite(PIN_LED_STOP, LOW);

  // LCD update
  lcd.clear();
  lcd.setCursor(0, 0);
  lcd.print("Pinhole Detector");
  lcd.setCursor(0, 1);
  lcd.print("System: RUNNING");
  lcd.setCursor(0, 2);
  lcd.print("Recording ambient...");

  // Record ambient light after relay stabilizes
  delay(500);
  int ldr1 = analogRead(PIN_LDR1);
  int ldr2 = analogRead(PIN_LDR2);
  ambientLight = (ldr1 + ldr2) / 2;
  ambientRecorded = true;

  lcd.setCursor(0, 2);
  lcd.print("Ambient: ");
  lcd.print(ambientLight);
  lcd.print("    ");

  Serial.print("[SYSTEM] Started, ambient light: ");
  Serial.println(ambientLight);

  publishState();
}

void stopSystem() {
  systemRunning = false;

  // Turn off outputs
  digitalWrite(PIN_LIGHT_RELAY, LOW);
  digitalWrite(PIN_MOTOR, LOW);
  digitalWrite(PIN_BUZZER, LOW);
  digitalWrite(PIN_LED_START, LOW);
  digitalWrite(PIN_LED_STOP, HIGH);
  buzzerActive = false;

  // LCD update
  lcd.clear();
  lcd.setCursor(0, 0);
  lcd.print("Pinhole Detector");
  lcd.setCursor(0, 1);
  lcd.print("System: STOPPED");
  lcd.setCursor(0, 2);
  lcd.print("                    ");
  lcd.setCursor(0, 3);
  lcd.print("                    ");

  Serial.println("[SYSTEM] Stopped");

  publishState();
}

void checkPinhole() {
  if (!ambientRecorded) return;

  int ldr1 = analogRead(PIN_LDR1);
  int ldr2 = analogRead(PIN_LDR2);
  int averageLight = (ldr1 + ldr2) / 2;

  // Check if light increased significantly (pinhole detected)
  if (averageLight > ambientLight + PINHOLE_THRESHOLD) {
    Serial.print("[DETECT] Pinhole! LDR1=");
    Serial.print(ldr1);
    Serial.print(" LDR2=");
    Serial.print(ldr2);
    Serial.print(" Avg=");
    Serial.print(averageLight);
    Serial.print(" Threshold=");
    Serial.println(ambientLight + PINHOLE_THRESHOLD);

    // Trigger alarm
    digitalWrite(PIN_BUZZER, HIGH);
    buzzerActive = true;
    buzzerStartTime = millis();

    // Update LCD
    lcd.setCursor(0, 3);
    lcd.print("PINHOLE DETECTED!");

    // Publish detection
    publishPinholeDetected(ldr1, ldr2, averageLight);
  }

  // Update LCD with current readings
  lcd.setCursor(0, 2);
  lcd.print("LDR:");
  lcd.print(averageLight);
  lcd.print(" T:");
  lcd.print(ambientLight + PINHOLE_THRESHOLD);
  lcd.print("    ");
}

void publishState() {
  if (!mqttClient.connected()) return;

  const char* state = systemRunning ? "running" : "stopped";
  bool published = mqttClient.publish(topicState, state, true);

  Serial.print("[MQTT] Published state: ");
  Serial.print(state);
  Serial.print(" -> ");
  Serial.println(published ? "OK" : "FAILED");
}

void publishPinholeDetected(int ldr1, int ldr2, int average) {
  if (!mqttClient.connected()) return;

  // Create JSON payload
  char payload[128];
  snprintf(payload, sizeof(payload),
           "{\"ldr1\":%d,\"ldr2\":%d,\"average\":%d,\"ambient\":%d,\"timestamp\":%lu}",
           ldr1, ldr2, average, ambientLight, millis());

  bool published = mqttClient.publish(topicPinhole, payload);

  Serial.print("[MQTT] Published pinhole detection: ");
  Serial.println(published ? "OK" : "FAILED");
  Serial.println(payload);
}

void updateLcdLine(int line, const char* text) {
  lcd.setCursor(0, line);
  lcd.print(text);
}

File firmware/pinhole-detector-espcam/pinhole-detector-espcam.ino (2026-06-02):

#include "esp_camera.h"
#include <WiFi.h>
#include <HTTPClient.h>
#include <PubSubClient.h>

#define PWDN_GPIO_NUM 32
#define RESET_GPIO_NUM -1
#define XCLK_GPIO_NUM 0
#define SIOD_GPIO_NUM 26
#define SIOC_GPIO_NUM 27
#define Y9_GPIO_NUM 35
#define Y8_GPIO_NUM 34
#define Y7_GPIO_NUM 39
#define Y6_GPIO_NUM 36
#define Y5_GPIO_NUM 21
#define Y4_GPIO_NUM 19
#define Y3_GPIO_NUM 18
#define Y2_GPIO_NUM 5
#define VSYNC_GPIO_NUM 25
#define HREF_GPIO_NUM 23
#define PCLK_GPIO_NUM 22

const char *wifiSsid = "pinhole-detector";
const char *wifiPassword = "pinhole123";
const char *serverUrl = "http://192.168.131.85:8000/api/images/receive/";
const char *mqttServer = "192.168.131.85";
const int mqttPort = 1883;
const char *mqttClientId = "pinhole-espcam";
const char *commandTopic = "pinhole/state";
const char *statusTopic = "pinhole/espcam/status";

WiFiClient wifiClient;
PubSubClient mqttClient(wifiClient);

bool capturing = false;
unsigned long lastCaptureAt = 0;
const unsigned long captureIntervalMs = 1000;

void publishStatus(const char *status) {
  if (mqttClient.connected()) {
    bool published = mqttClient.publish(statusTopic, status, true);
    Serial.print("[MQTT] Status publish '");
    Serial.print(status);
    Serial.print("' -> ");
    Serial.println(published ? "OK" : "FAILED");
  } else {
    Serial.print("[MQTT] Cannot publish status, disconnected: ");
    Serial.println(status);
  }
}

void onMqttMessage(char *topic, byte *payload, unsigned int length) {
  String message;
  for (unsigned int i = 0; i < length; i++) {
    message += (char)payload[i];
  }
  message.trim();
  message.toLowerCase();

  Serial.print("[MQTT] Message on topic ");
  Serial.print(topic);
  Serial.print(": ");
  Serial.println(message);

  if (message == "running") {
    capturing = true;
    Serial.println("[CONTROL] Capture started");
    publishStatus("capturing");
  }

  if (message == "stopped") {
    capturing = false;
    Serial.println("[CONTROL] Capture stopped");
    publishStatus("idle");
  }
}

void connectWiFi() {
  Serial.print("[WIFI] Connecting to ");
  Serial.println(wifiSsid);
  WiFi.mode(WIFI_STA);
  WiFi.begin(wifiSsid, wifiPassword);

  while (WiFi.status() != WL_CONNECTED) {
    Serial.print(".");
    delay(500);
  }

  Serial.println();
  Serial.println("[WIFI] Connected");
  Serial.print("[WIFI] IP address: ");
  Serial.println(WiFi.localIP());
  Serial.print("[WIFI] RSSI: ");
  Serial.print(WiFi.RSSI());
  Serial.println(" dBm");
}

void connectMqtt() {
  mqttClient.setServer(mqttServer, mqttPort);
  mqttClient.setCallback(onMqttMessage);

  while (!mqttClient.connected()) {
    Serial.print("[MQTT] Connecting to ");
    Serial.print(mqttServer);
    Serial.print(":");
    Serial.println(mqttPort);

    if (mqttClient.connect(mqttClientId)) {
      Serial.println("[MQTT] Connected");
      mqttClient.subscribe(commandTopic);
      Serial.print("[MQTT] Subscribed to ");
      Serial.println(commandTopic);
      publishStatus("idle");
    } else {
      Serial.print("[MQTT] Connection failed, state=");
      Serial.println(mqttClient.state());
      delay(1000);
    }
  }
}

void setupCamera() {
  Serial.println("[CAMERA] Initializing camera");
  camera_config_t config;
  config.ledc_channel = LEDC_CHANNEL_0;
  config.ledc_timer = LEDC_TIMER_0;
  config.pin_d0 = Y2_GPIO_NUM;
  config.pin_d1 = Y3_GPIO_NUM;
  config.pin_d2 = Y4_GPIO_NUM;
  config.pin_d3 = Y5_GPIO_NUM;
  config.pin_d4 = Y6_GPIO_NUM;
  config.pin_d5 = Y7_GPIO_NUM;
  config.pin_d6 = Y8_GPIO_NUM;
  config.pin_d7 = Y9_GPIO_NUM;
  config.pin_xclk = XCLK_GPIO_NUM;
  config.pin_pclk = PCLK_GPIO_NUM;
  config.pin_vsync = VSYNC_GPIO_NUM;
  config.pin_href = HREF_GPIO_NUM;
  config.pin_sscb_sda = SIOD_GPIO_NUM;
  config.pin_sscb_scl = SIOC_GPIO_NUM;
  config.pin_pwdn = PWDN_GPIO_NUM;
  config.pin_reset = RESET_GPIO_NUM;
  config.xclk_freq_hz = 20000000;
  config.pixel_format = PIXFORMAT_JPEG;
  config.frame_size = FRAMESIZE_UXGA;
  config.jpeg_quality = 10;
  config.fb_count = 2;
  config.grab_mode = CAMERA_GRAB_LATEST;

  esp_err_t cameraStatus = esp_camera_init(&config);
  if (cameraStatus != ESP_OK) {
    Serial.print("[CAMERA] Init failed, error=0x");
    Serial.println(cameraStatus, HEX);
    while (true) {
      delay(1000);
    }
  }

  Serial.println("[CAMERA] Ready");
}

void sendPhoto() {
  Serial.println("[CAPTURE] Taking photo");
  camera_fb_t *frame = esp_camera_fb_get();
  if (!frame) {
    Serial.println("[CAPTURE] Camera frame failed");
    publishStatus("camera_error");
    return;
  }

  Serial.print("[CAPTURE] Frame size: ");
  Serial.print(frame->len);
  Serial.println(" bytes");
  Serial.print("[HTTP] Uploading to ");
  Serial.println(serverUrl);

  HTTPClient http;
  http.begin(serverUrl);
  http.addHeader("Content-Type", "image/jpeg");
  http.addHeader("X-Device-ID", mqttClientId);

  int responseCode = http.POST(frame->buf, frame->len);

  Serial.print("[HTTP] Response code: ");
  Serial.println(responseCode);

  if (responseCode >= 200 && responseCode < 300) {
    Serial.println("[HTTP] Upload successful");
    publishStatus("image_sent");
  } else {
    Serial.print("[HTTP] Upload failed: ");
    Serial.println(http.errorToString(responseCode));
    publishStatus("upload_failed");
  }

  http.end();
  esp_camera_fb_return(frame);
}

void setup() {
  Serial.begin(115200);
  delay(1000);
  Serial.println();
  Serial.println("[BOOT] ESP32-CAM pinhole detector starting");
  Serial.print("[BOOT] Device ID: ");
  Serial.println(mqttClientId);
  setupCamera();
  connectWiFi();
  connectMqtt();
  Serial.println("[BOOT] Setup complete");
}

void loop() {
  if (WiFi.status() != WL_CONNECTED) {
    Serial.println("[WIFI] Disconnected, reconnecting");
    connectWiFi();
  }

  if (!mqttClient.connected()) {
    Serial.println("[MQTT] Disconnected, reconnecting");
    connectMqtt();
  }

  mqttClient.loop();

  if (capturing && millis() - lastCaptureAt >= captureIntervalMs) {
    lastCaptureAt = millis();
    sendPhoto();
  }
}

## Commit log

2026-05-30 about to espCAM
    [Front_Device.SLDPRT, light.SLDPRT, light_casing.SLDPRT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]
2026-06-02 modifying esp32 cam
